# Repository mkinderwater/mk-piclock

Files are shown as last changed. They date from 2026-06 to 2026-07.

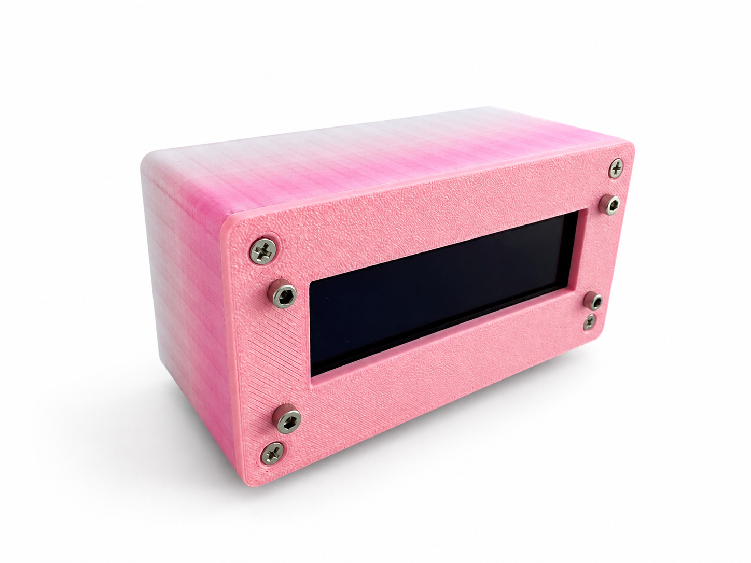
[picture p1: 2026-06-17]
side-picture.png

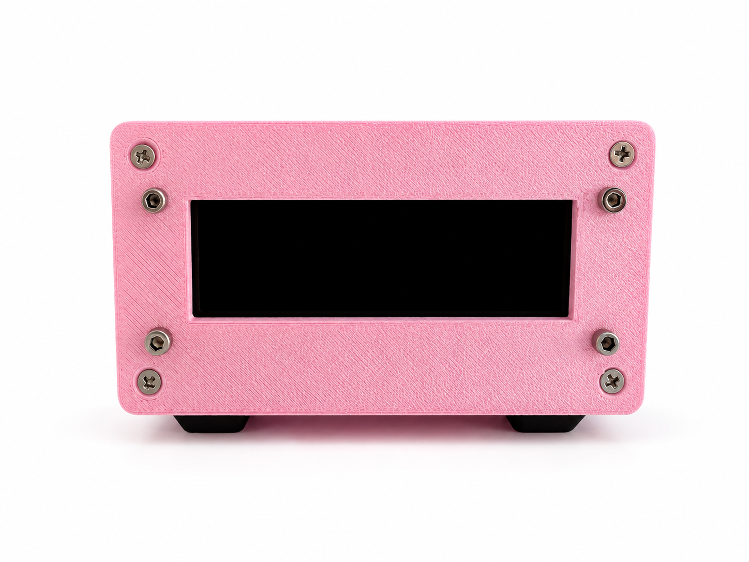
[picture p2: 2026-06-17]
front-picture.png

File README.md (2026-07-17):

# mk-piclock v1.8.1

mk-piclock is a native C bedside alarm clock for Raspberry Pi Zero and Zero 2 W. It drives a 256x64 SSD1322 OLED, MAX98357A I2S amplifier, speaker, TTP223B touch sensor, and optional RGB LED.

The project was created for my daughter Rylie. It is designed to behave like a simple bedside appliance, not a general-purpose computer.

## What's new in v1.8.1

- Standardized every GUI card heading with the same divider, spacing, and title alignment.
- Changed inactive sound status from `Quiet` to `None` across the GUI.
- Added consistent spacing between RGB Lighting and Global Controls.
- Removed the duplicate divider beneath the Web password description.
- Added matching headings to Story playback and Activity history.
- Updated browser asset versions so the polished GUI loads without stale cached files.
- Retained the production display and code cleanup introduced in v1.8.0.
- Kept HTTP API 1.25 and private IPC 16.

## Features

### Clock and display

- Large 12-hour or 24-hour clock
- Full date under the time
- Blinking colon
- Day and bedtime image libraries
- Automatic image rotation
- Plain-text Wi-Fi and alarm status footer
- Blinking `W.OFF` warning when wireless is disconnected
- OLED brightness control
- Separate bedtime schedule and brightness
- Yellow, green, or white panel selection for browser previews
- Built-in and uploaded TrueType or OpenType fonts
- Exact 256x64 live framebuffer preview on the Home page

The normal footer uses one baseline:

```text
W.095 | ALARM ON                  FRIDAY, JULY 17 2026
```

The last IPv4 octet is zero-padded. The alarm label changes between `ALARM ON` and `ALARM OFF`. When `wlan0` loses carrier or its IPv4 address, `W.OFF` blinks. The clock and alarms continue locally, but the browser and network time synchronization remain unavailable until Wi-Fi returns.

### Alarms

- Seven independent alarm slots
- Per-alarm time and weekday selection
- Specific or random uploaded music
- Separate starting and final volume
- Volume ramp across the song
- Next alarm shown on Home and System
- Last successful alarm recorded on System

#### Alarm safety

When an alarm starts:

- the selected song repeats until the touch sensor is pressed
- browser stop controls cannot dismiss the alarm
- an unreadable or missing song falls back to the protected built-in alarm
- the alarm stops after 30 minutes if nobody presses the sensor

The fallback alarm is installed at:

```text
/opt/mk-piclock/assets/default-alarm.mp3
```

It is retained during factory reset and is not part of the user music library.

### Kid-friendly touch control

- Press while an alarm is active: dismiss the alarm
- Short press while music or a story is playing: stop the audio
- Hold, then release: play a random song
- Keep holding the sensor: open the OLED network diagnostic screen
- Tap while diagnostics are open: close diagnostics
- Ten short taps within eight seconds: play a random story when Story Mode is enabled
- Any touch press: blink the RGB LED using the selected touch-feedback colour

The music action runs only when the sensor is released. Keep holding to open diagnostics instead, so the same press cannot start music. A diagnostic hold is not counted toward Story Mode.

Alarms cannot be dismissed from the browser. The physical touch sensor must be pressed.

#### OLED network diagnostics

Simply hold down the touch sensor to open the diagnostic screen. It shows:

- Wi-Fi network name
- Wi-Fi signal strength
- IP address
- hostname

It closes after 30 seconds or immediately when the touch sensor is tapped. Network values refresh while the screen is open.

### Bedtime behaviour

Bedtime mode uses its own schedule, image library, and brightness. It lets the clock remain useful at night without keeping the OLED unnecessarily bright.

Day Images and Bedtime Images are stored separately. During bedtime, the clock uses bedtime artwork and the configured bedtime brightness. Parents can disable touch-started music during bedtime while leaving alarms enabled.

### Messages

Parents can send a message to the OLED:

- immediately
- after 10, 30, or 60 seconds
- at a browser-local date and time within the next 30 days

A message can use:

- text only
- a specific Day Image
- a specific Bedtime Image
- a random Day Image
- a random Bedtime Image
- an image without text

One future message can be pending. A new scheduled message replaces the existing one. Pending messages survive a core restart. Each message can optionally play the built-in short chime when it appears. The chime is skipped when other audio is already playing.

The preview is rendered by `mk-piclock-core` using the same framebuffer, font measurements, word wrapping, image placement, centring, grayscale, and brightness rules as the physical OLED.

### Images

Day Images and Bedtime Images each support:

- PNG upload
- OLED conversion
- paged library review
- individual deletion
- delete all
- download all original PNG files as a ZIP

The download ZIP excludes converted `.raw` files.

### Music

Uploaded MP3 files are decoded and re-encoded inside `mk-piclock-api`. No shell command or external encoder is launched.

The recommended profile is:

- mono
- 96 kbps CBR
- 44.1 kHz
- 16 kHz low-pass

The Music page includes:

- multiple-file upload
- selected-file count and total upload size before upload
- upload and processing progress for queued and active jobs
- play, stop, and delete controls
- global volume
- optional encoding settings
- title, artist, album, year, track, genre, duration, bitrate, sample rate, channel, MPEG layer, and file size when available

Long `Title - Artist` text scrolls across the OLED. Short text remains centred.

Before OLED rendering, the title and artist are filtered against the built-in 5x7 glyph set. Unsupported Unicode, emoji, and symbols are omitted instead of becoming question marks. Filtering affects only the OLED copy. Original ID3 metadata remains available in the browser and API.

#### Upload queue rule

A batch of MP3 files may be uploaded at one time. A new upload is refused while any song from the current batch is queued or processing.

The full selection is validated and staged before any job is queued. If staging or queueing fails, the staged files are rolled back instead of leaving a partial batch. This keeps upload validation and transcoding from competing for CPU, memory, and storage on the Raspberry Pi.

**Clear Queue** deletes waiting jobs and their temporary source files. It does not interrupt the file currently transcoding.

### Stories

Story Mode uses a separate MP3 library stored under `assets/stories`. It can be enabled or disabled by a parent from the Stories page and has its own volume control.

When the touch sensor is tapped ten times within eight seconds:

1. a random story is selected
2. the OLED clears and shows up to five random Bedtime Images
3. the configurable intro message appears, defaulting to `STORY MODE!`
4. after three seconds, the selected story title appears in the normal clock footer
5. after four more seconds, the standard date returns while the story keeps playing

A single touch stops the story. Stories are not used by alarms and are not included in backups.

### RGB activity lighting

A common-cathode RGB LED can use a separate profile for each activity:

- Alarm
- Bedtime
- Message
- Music
- Daytime
- Stories

Each profile supports a solid colour, a fade between two colours, or rainbow mode. Brightness and the full effect-cycle time are configurable. The Lighting page can preview unsaved settings for ten seconds and includes red, green, blue, and white wiring tests.

Touch feedback is handled as a high-priority temporary LED scene while the touch sensor is pressed. Its colour and brightness live under Lighting, Global Controls, so it can stay consistent no matter which activity profile is currently active. The default touch feedback is a white blink.

Global controls provide a master switch, maximum brightness, per-channel calibration, optional idle-off behaviour, a gradual fade before bedtime, and touch-blink settings. Profile previews and wiring tests may temporarily bypass the master switch. A touch press briefly takes priority while pressed, then the normal alarm, message, story, music, bedtime, or daytime scene resumes.

The driver uses 200 Hz batched trailing-edge software PWM with 32 stable duty levels. A modest real-time priority is applied only to the LED timing thread, and missed low-brightness pulses are skipped rather than emitted late. Scene changes crossfade over 350 ms except alarms, which apply immediately. Repeated GPIO write failures disable lighting and appear in status and diagnostics.

The runtime priority after touch feedback is Alarm, Message, Stories, Music, Bedtime, then Daytime.

## Web interface

The GUI is organized by task.

### Everyday

- Home
- Alarms
- Messages
- Music
- Lighting
- Stories
- Day Images
- Bedtime Images

### Settings

- Display
- System

### Optional password

The web interface opens directly when no password exists. When a password is configured, the GUI asks for it before loading clock controls. The password can be set, changed, or removed from System. It is intentionally simple and stored as plain text for use only on a trusted home network.

### Always-visible confirmations

Save, test, delete, upload, and other action confirmations appear in a fixed floating notice. Feedback remains readable at any scroll position instead of appearing inside a section that may be off-screen.

### System diagnostics

The System page provides live diagnostics without launching external commands.

#### Network

- IP address
- hostname
- SSID
- active interface
- Wi-Fi signal percentage and dBm

#### Time

- system-time validity
- NTP synchronization state
- a prominent Home-page warning when time is not synchronized

#### Device identity

- short Inventory ID derived from the Raspberry Pi board serial
- full Raspberry Pi board serial
- Raspberry Pi board revision
- OS machine ID
- CPU signature for processor identification

Use the Inventory ID or Raspberry Pi serial to track a physical clock. The OS machine ID can change after reimaging, and the CPU signature is not unique.

#### Release and Raspberry Pi platform

- installed release version
- HTTP API version
- API compile date and time
- Raspberry Pi model
- operating system name
- OS version and codename
- kernel version
- CPU architecture
- system uptime
- CPU temperature

#### Storage and SD card

- used, available, and total system storage
- Day Images directory size and file count
- Bedtime Images directory size and file count
- music directory size and file count
- stories directory size and file count
- fonts directory size and file count
- system drive
- root partition and filesystem
- root read/write state
- boot partition, filesystem, and mount point
- SD-card device and type
- product name
- capacity
- manufacturer ID
- OEM ID
- serial number
- manufacture date
- CID

#### Service and clock health

- API health
- core connection
- OLED state
- touch-sensor state
- next alarm
- last successful alarm

**Download Diagnostic Report** saves the same information as a text file for support or troubleshooting.

### Backup and reset

The System page can:

- download a backup ZIP
- restore a backup created by mk-piclock
- factory reset settings and user-added assets

Backups include:

- alarms
- display and bedtime settings
- clock name and personalization
- scheduled-message data
- Day Images
- Bedtime Images
- uploaded fonts

Restore accepts only a validated mk-piclock backup ZIP. Paths, metadata, stored entries, sizes, and CRC values are checked before files are activated. Existing settings, images, and fonts are staged first and restored if the operation fails. Uploaded music and stories are not included in backups. Restore has no music or story handling, and both current libraries remain unchanged.

Restore is blocked while an alarm is active. Factory reset is blocked while an alarm is active or music is processing. Factory reset still removes uploaded music and stories. The protected fallback alarm remains installed after a factory reset.

### Help

- Recent Activity

Technical details remain available in collapsed sections so normal controls stay simple.

## Network access

The web interface opens directly when no password is configured. A simple optional password can be set or removed from System. It is stored as plain text on the clock and is intended only to keep casual users out of the controls.

Any device that can reach TCP port 8080 can view and change the clock. Keep the clock on a trusted home network.

Do not:

- forward port 8080 through the router
- expose the clock directly to the internet
- place it on an untrusted guest or public network

The API still runs as a restricted system account and communicates with the hardware process through a private Unix socket.

## Architecture

mk-piclock uses two native services.

### `mk-piclock-core`

Owns:

- OLED and SPI
- GPIO and touch input
- ALSA audio playback
- alarms
- clock and message rendering
- bedtime behaviour
- persistent clock configuration
- event logging

### `mk-piclock-api`

Owns:

- local web GUI
- HTTP API
- upload validation
- PNG conversion
- MP3 transcoding
- music, story, and image libraries
- OpenAPI document

The services communicate through:

```text
/run/mk-piclock/core.sock
```

The private binary protocol is IPC version 16.

## Command-free runtime

The running core and API do not use:

- `exec*()`
- `system()`
- `popen()`
- `posix_spawn()`
- `fork()` or `vfork()`

MP3 decoding, MP3 encoding, ZIP backup and restore, network inspection, platform reporting, and storage inspection run in-process through libraries and direct Linux interfaces.

The Makefile and installation steps use normal shell tools. This restriction applies to the installed runtime services.

## Time and NTP on Raspberry Pi OS Trixie

mk-piclock reads the Linux system clock. It does not contact an NTP server itself.

Raspberry Pi OS Lite based on Debian 13 Trixie normally uses `systemd-timesyncd` for network time synchronization. Set the timezone and confirm synchronization during installation:

```bash
sudo timedatectl set-timezone America/Edmonton
sudo timedatectl set-ntp true

timedatectl status
timedatectl show -p NTPSynchronized
```

Expected results include:

```text
System clock synchronized: yes
NTP service: active
NTPSynchronized=yes
```

Without a battery-backed real-time clock, correct time after a power loss depends on the Pi restoring time and reaching a time source.

## Supported platform

Recommended operating system:

```text
Raspberry Pi OS Lite
Debian 13 Trixie
```

Recommended hardware:

- Raspberry Pi Zero W or Zero 2 W
- SSD1322 256x64 OLED
- MAX98357A I2S amplifier
- 4-ohm, 3-watt speaker
- TTP223B touch sensor
- common-cathode RGB LED with one resistor per colour channel

See `pinouts.md` before applying power.

## Build dependencies

```bash
sudo apt update
sudo apt install --no-install-recommends -y \
  build-essential \
  pkg-config \
  libgpiod-dev \
  libpng-dev \
  libfreetype-dev \
  libasound2-dev \
  libmpg123-dev \
  libmp3lame-dev \
  libmicrohttpd-dev \
  unzip
```

`libmp3lame-dev` provides the in-process MP3 encoder.

## Quick installation

After configuring SPI and the MAX98357A overlay as described in `INSTALL.md`:

```bash
make clean
make -j2
make install
sudo systemctl restart mk-piclock-core.service mk-piclock-api.service
```

Open:

```text
http://<clock-ip>:8080/
```

Do not run `sudo make install`. The Makefile invokes `sudo` only for privileged installation steps.

## Storage

The installer and services only create the storage and runtime directories used by the clock. No old `auth`, `faces`, `bedtime-faces`, or `bedtime_faces` directories are created.

```text
/opt/mk-piclock/assets/images
/opt/mk-piclock/assets/bedtime-images
/opt/mk-piclock/assets/music
/opt/mk-piclock/assets/music/.processing
/opt/mk-piclock/assets/stories
/opt/mk-piclock/assets/fonts
/opt/mk-piclock/assets/default-alarm.mp3
/opt/mk-piclock/config/clock.conf
/opt/mk-piclock/config/event.log
/run/mk-piclock/core.sock
```

## Service logs

```bash
sudo journalctl -b -u mk-piclock-core.service -n 100 --no-pager
sudo journalctl -b -u mk-piclock-api.service -n 100 --no-pager
```

Follow both services:

```bash
sudo journalctl -f \
  -u mk-piclock-core.service \
  -u mk-piclock-api.service
```

## Known limitations

- The MAX98357A and speaker may make a small pop when audio starts or stops.
- **Clear Queue** removes waiting MP3 jobs but does not cancel the active transcode.
- The clock has no built-in battery-backed real-time clock. Accurate time after startup depends on Linux time restoration or NTP. The GUI warns when the clock is not synchronized.
- Restore accepts backup ZIP files generated by mk-piclock. Other ZIP compression formats are rejected.
- The optional GUI password is stored as plain text and is not strong security. Keep the clock on a trusted home network and do not expose port 8080 to the internet.
- USB-C power behaviour depends on the power board used in the enclosure. A USB-A to USB-C cable is often the safest choice for simple 5 V boards that do not implement USB-C power negotiation correctly.
- The physical OLED colour is fixed by the panel. The GUI colour choice changes browser previews only.
- Some network or SD-card fields can show **Unavailable** when the Linux driver does not expose the value.
- The API service sandbox remains restricted. Network detection uses direct IPv4 ioctls instead of netlink discovery.

## Versions

```text
Product:     1.8.1
HTTP API:    1.25
Private IPC: 16
```

Install the core and API from the same release, then restart both services. Installation replaces the complete web tree, and every GUI asset uses `Cache-Control: no-store`, preventing retired or cached files from surviving an upgrade.

## Documentation

- Build and install: `INSTALL.md`
- Hardware wiring: `pinouts.md`
- Version history: `CHANGELOG.md`
- HTTP API: `ADDON_API.md`
- OpenAPI schema: `api/openapi-v1.json`
- Current release summary: `RELEASE_NOTES.md`

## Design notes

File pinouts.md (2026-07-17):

# mk-piclock v1.8.1 Pinouts

This document covers the Raspberry Pi GPIO header, SSD1322 OLED, MAX98357A I2S amplifier, speaker, TTP223B touch sensor, and common-cathode RGB LED used by mk-piclock.

The software uses **BCM GPIO numbering**. Physical pin numbers refer to the Raspberry Pi 40-pin header.

## Complete connection table

| Device | Device signal | Raspberry Pi signal | BCM GPIO | Physical pin | Direction |
| --- | --- | --- | ---: | ---: | --- |
| External 5 V supply | +5 V | Pi 5 V input | - | 4 | Supply to Pi |
| External 5 V supply | GND | Pi ground | - | 9 | Supply to Pi |
| SSD1322 OLED | VCC | 3.3 V | - | 1 | Pi to OLED |
| SSD1322 OLED | GND | Ground | - | 6 | Common ground |
| SSD1322 OLED | DIN / MOSI / D1 | SPI0 MOSI | 10 | 19 | Pi to OLED |
| SSD1322 OLED | CLK / SCLK / D0 | SPI0 SCLK | 11 | 23 | Pi to OLED |
| SSD1322 OLED | CS | SPI0 CE0 | 8 | 24 | Pi to OLED |
| SSD1322 OLED | DC / A0 | Data/command | 25 | 22 | Pi to OLED |
| SSD1322 OLED | RST / RES | Reset | 27 | 13 | Pi to OLED |
| MAX98357A amp | VIN | 5 V | - | 2 | Pi to amp |
| MAX98357A amp | GND | Ground | - | 14 | Common ground |
| MAX98357A amp | BCLK | PCM clock | 18 | 12 | Pi to amp |
| MAX98357A amp | LRC / LRCLK / WS | PCM frame sync | 19 | 35 | Pi to amp |
| MAX98357A amp | DIN | PCM data | 21 | 40 | Pi to amp |
| MAX98357A amp | SD / EN | Not connected | - | - | Module default |
| TTP223B touch | VCC | 3.3 V | - | 17 | Pi to sensor |
| TTP223B touch | GND | Ground | - | 39 | Common ground |
| TTP223B touch | OUT / SIG | Digital input | 20 | 38 | Sensor to Pi |
| RGB LED | Red anode through resistor | Digital PWM output | 5 | 29 | Pi to LED |
| RGB LED | Green anode through resistor | Digital PWM output | 6 | 31 | Pi to LED |
| RGB LED | Blue anode through resistor | Digital PWM output | 13 | 33 | Pi to LED |
| RGB LED | Common cathode | Ground | - | 30 | Common ground |
| Speaker | `+` | MAX98357A `SPK+` | - | - | Amp to speaker |
| Speaker | `-` | MAX98357A `SPK-` | - | - | Amp to speaker |

The external regulated 5 V supply powers the Raspberry Pi through physical pin 4, with supply ground on physical pin 9. The amplifier uses physical pins 2 and 14, so no power connector is physically shared. Raspberry Pi pins 2 and 4 are still electrically connected to the same internal 5 V rail, and all ground pins are common. Do not connect USB power while the header supply is connected.

The build has two 3.3 V consumers: OLED VCC and TTP223B VCC. They use separate Raspberry Pi header pins. Leave the MAX98357A SD / EN pad unconnected.

## Raspberry Pi 40-pin header map

```text
                         Raspberry Pi GPIO header

OLED VCC       <- 3.3V       (1)  (2)  5V          -> MAX98357A VIN
                              (3)  (4)  5V          <- EXTERNAL +5V INPUT
                              (5)  (6)  GND         -> OLED GND
                              (7)  (8)
EXTERNAL GND    -> GND         (9) (10)
                             (11) (12) GPIO18       -> MAX98357A BCLK
OLED RST       <- GPIO27    (13) (14) GND          -> MAX98357A GND
                             (15) (16)
TTP223B VCC    <- 3.3V      (17) (18)
OLED MOSI      <- GPIO10    (19) (20) GND
                 GPIO9     (21) (22) GPIO25       -> OLED DC
OLED SCLK      <- GPIO11    (23) (24) GPIO8        -> OLED CS
                 GND       (25) (26)
                             (27) (28)
RGB RED        <- GPIO5     (29) (30) GND          -> RGB COMMON CATHODE
RGB GREEN      <- GPIO6     (31) (32)
RGB BLUE       <- GPIO13    (33) (34) GND
MAX98357A LRC  <- GPIO19    (35) (36)
                             (37) (38) GPIO20       -> TTP223B OUT
TTP223B GND    <- GND       (39) (40) GPIO21       -> MAX98357A DIN
```

Pin 1 is the 3.3 V corner pin. Confirm the header orientation before applying power.

## SSD1322 OLED

The core opens `/dev/spidev0.0`, which uses SPI0 CE0.

```text
SSD1322 OLED          Raspberry Pi
-----------------------------------------------
VCC                -> 3.3 V, physical pin 1
GND                -> GND, physical pin 6
DIN / MOSI / D1    -> GPIO10, physical pin 19
CLK / SCLK / D0    -> GPIO11, physical pin 23
CS                 -> GPIO8 CE0, physical pin 24
DC / A0            -> GPIO25, physical pin 22
RST / RES           -> GPIO27, physical pin 13
```

OLED settings compiled into `mk-piclock.c`:

```text
SPI device: /dev/spidev0.0
SPI mode:   0
SPI speed:  4 MHz
DC:         BCM GPIO25
RST:        BCM GPIO27
```

Notes:

- The OLED does not use SPI MISO. GPIO9, physical pin 21, remains unused.
- Connect CS to CE0. Do not tie CS low when using `/dev/spidev0.0` unless the specific module requires it and no other SPI device shares the bus.
- SSD1322 module header order varies. Follow the signal labels printed on the module, not the position shown in a seller photograph.
- This project wiring uses 3.3 V for the OLED. Confirm the module is configured for 4-wire SPI.

## MAX98357A I2S amplifier

```text
MAX98357A             Raspberry Pi
-----------------------------------------------
VIN                -> 5 V, physical pin 2
GND                -> GND, physical pin 14
BCLK               -> GPIO18, physical pin 12
LRC / LRCLK / WS   -> GPIO19, physical pin 35
DIN                -> GPIO21, physical pin 40
SD / EN            -> Not connected
```

Required `/boot/firmware/config.txt` settings:

```ini
dtparam=audio=off
dtoverlay=max98357a,no-sdmode
```

`no-sdmode` means mk-piclock does not control the amplifier SD or EN input from a GPIO. On the tested module, leaving SD / EN unconnected allows the module's onboard bias network to enable playback and select its default mono mix. Do not connect SD / EN to a Raspberry Pi GPIO or directly to 3.3 V.

### Audio startup click

A small click when playback starts is accepted in this release. SD / EN remains unconnected, and mk-piclock does not add amplifier switching, a persistent silence stream, or other click-suppression logic.

## Speaker

Connect the speaker only to the MAX98357A output:

```text
MAX98357A SPK+  -> Speaker +
MAX98357A SPK-  -> Speaker -
```

Important:

- Do not connect either speaker terminal to Raspberry Pi ground.
- The MAX98357A speaker output is differential.
- Use one compatible 4 to 8 ohm speaker.
- Disconnect power before changing speaker or amplifier wiring.

## TTP223B touch sensor

```text
TTP223B               Raspberry Pi
-----------------------------------------------
VCC                -> 3.3 V, physical pin 17
GND                -> GND, physical pin 39
OUT / SIG          -> GPIO20, physical pin 38
```

The core reads GPIO20 as an active-high input and applies software debounce.

```text
Short press:   stop current audio
Hold 3 seconds: play random uploaded music
```

Power the TTP223B from **3.3 V**. Do not power it from 5 V while OUT is directly connected to a Raspberry Pi GPIO.

## Common-cathode RGB LED

```text
RGB LED                Raspberry Pi
Red anode, resistor -> GPIO5, physical pin 29
Green anode, resistor -> GPIO6, physical pin 31
Blue anode, resistor -> GPIO13, physical pin 33
Common cathode      -> GND, physical pin 30
```

Use one 220 to 330 ohm current-limiting resistor on each colour channel. The software drives the three anodes active-high using 200 Hz batched trailing-edge PWM with 32 stable duty levels. This wiring is for a common-cathode LED. A common-anode module requires inverted output logic and is not supported by this release.

The Lighting page includes direct red, green, blue, and white wiring tests. These tests temporarily bypass the master switch, global brightness ceiling, and colour calibration so each physical channel can be checked independently.

## GPIOs used by mk-piclock

| BCM GPIO | Physical pin | Purpose |
| ---: | ---: | --- |
| 5 | 29 | RGB LED red |
| 6 | 31 | RGB LED green |
| 8 | 24 | OLED SPI CE0 / CS |
| 10 | 19 | OLED SPI MOSI |
| 11 | 23 | OLED SPI clock |
| 13 | 33 | RGB LED blue |
| 18 | 12 | MAX98357A BCLK |
| 19 | 35 | MAX98357A LRC / LRCLK |
| 20 | 38 | TTP223B OUT |
| 21 | 40 | MAX98357A DIN |
| 25 | 22 | OLED DC |
| 27 | 13 | OLED reset |

## Pre-power checklist

- Confirm the external supply is a regulated 5 V source suitable for the Pi and amplifier load.
- Connect external +5 V to physical pin 4 and external ground to physical pin 9.
- Do not connect USB power while the GPIO header supply is connected.
- Confirm pin 1 orientation on the Raspberry Pi header.
- Confirm every module shares Raspberry Pi ground.
- Confirm the OLED VCC wire is on 3.3 V, not a GPIO.
- Confirm the touch sensor VCC wire is on 3.3 V.
- Confirm the RGB LED is common-cathode and each colour has a current-limiting resistor.
- Confirm the amplifier SD / EN pad is not connected.
- Confirm amplifier DIN is connected to GPIO21, physical pin 40, and is not tied to 3.3 V.
- Confirm the speaker connects to `SPK+` and `SPK-`, not ground.
- Check for solder bridges before applying power.
- Enable SPI and the MAX98357A overlay before starting the services.

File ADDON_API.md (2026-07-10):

# mk-piclock HTTP API 1.25

The GUI and add-ons use the HTTP API on port 8080.

```text
http://<clock-ip>:8080/api/v1
```

Most routes are directly available when no password is configured. When a password exists, authenticate through `/api/v1/auth/login`; the API returns a session cookie used by the GUI. The password is stored as plain text and is intended only for a trusted home network. Do not expose port 8080 to the internet.

## Optional password

```http
GET  /api/v1/auth/status
POST /api/v1/auth/login
POST /api/v1/auth/password
```

`GET /api/v1/auth/status` reports whether a password exists and whether the current browser cookie is valid. `POST /api/v1/auth/login` accepts `password`. `POST /api/v1/auth/password` sets a new password or removes it when `password` is empty. The discovery endpoint and the two status/login routes remain public so the GUI can decide whether to show the prompt.

## Discovery and status

```http
GET /api/v1
GET /api/v1/capabilities
GET /api/v1/openapi.json
GET /api/v1/health
GET /api/v1/status
GET /api/v1/diagnostics
GET /api/v1/diagnostics/report
```

## Images

```http
GET  /api/v1/assets/images
GET  /api/v1/assets/bedtime-images
GET  /api/v1/assets/images/source?file=<raw-name>
GET  /api/v1/assets/bedtime-images/source?file=<raw-name>
GET  /api/v1/assets/images/download
GET  /api/v1/assets/bedtime-images/download
POST /api/v1/assets/images/upload
POST /api/v1/assets/bedtime-images/upload
POST /api/v1/assets/images/delete
POST /api/v1/assets/bedtime-images/delete
POST /api/v1/assets/images/delete-all
POST /api/v1/assets/bedtime-images/delete-all
```

The Day and Bedtime download routes return ZIP archives containing only original PNG files.

## Music

```http
GET  /api/v1/assets/music
POST /api/v1/assets/music/upload
GET  /api/v1/assets/music/jobs
POST /api/v1/assets/music/jobs/clear
POST /api/v1/assets/music/delete
POST /api/v1/assets/music/delete-all
```

MP3 upload settings include bitrate, sample rate, and low-pass frequency. One request may include 1 to 32 MP3 files. The full selection is validated and queued as one batch, and uploads are refused while any job is queued or processing. `POST /api/v1/assets/music/jobs/clear` removes waiting jobs but does not interrupt the active transcoder.

## Display and messages

```http
POST /api/v1/display/action
GET  /api/v1/display/preview
POST /api/v1/display/brightness-preview
POST /api/v1/display/message
POST /api/v1/display/message/preview
```

`POST /api/v1/display/message/preview` accepts `image_file`, `image_bedtime`, and `message_text`, then returns the exact packed 4-bit 256x64 framebuffer without changing the physical OLED.

Messages accept:

```text
image_file=<image raw filename, optional; empty selects a random image>
image_bedtime=0 for Day Images or 1 for Bedtime Images
message_text=<optional text; an image-only message is allowed>
delay_seconds=0, 10, 30, or 60
scheduled_at=<Unix timestamp, optional, within 30 days>
notification_sound=0 or 1; 1 plays the built-in chime when displayed
```

`GET /api/v1/diagnostics` returns release and compile information, network and NTP state, platform, device-identity, and operating-system details, used and available storage, asset directory sizes and file counts, root and boot filesystem details, SD-card identity, temperature, core/API, OLED, touch, and alarm health. `GET /api/v1/diagnostics/report` downloads the same information as text. Diagnostics are gathered in-process from Linux APIs and files under `/etc`, `/proc`, and `/sys`; the API does not launch system commands.

## Backup, restore, and reset

```http
GET  /api/v1/backup/download
POST /api/v1/backup/restore
POST /api/v1/factory-reset
```

Restore expects one multipart ZIP created by the download route. Backup ZIPs contain configuration, images, and fonts but exclude uploaded music and stories. Music and stories are outside the backup and restore system, so restore leaves both current libraries unchanged. Factory reset requires `confirm=RESET`. Restore and reset are refused while an alarm is active. Factory reset is also refused while music is processing.

## Configuration

```http
POST /api/v1/config/alarms
POST /api/v1/config/audio
POST /api/v1/config/personalization
POST /api/v1/config/display
POST /api/v1/config/led
```

Display configuration accepts `bedtime_music_enabled=0` to block touch-started and browser-started music during bedtime. Alarms remain enabled.

## Alarm behaviour

Alarms loop until the physical touch sensor is pressed or the 30-minute safety limit is reached. Browser stop requests return HTTP 409 while an alarm is active. If the selected MP3 is missing or unreadable, the protected built-in alarm is used.

`GET /api/v1/status` includes `next_alarm_at`, `next_alarm_text`, `last_successful_alarm`, and `bedtime_music_enabled`.

## RGB lighting

Save one activity profile:

```http
POST /api/v1/config/led
Content-Type: application/x-www-form-urlencoded

scene=alarm&effect=fade&brightness=100&color1=%23ff0000&color2=%23ffa000
```

Valid scenes are `alarm`, `bedtime`, `message`, `music`, `daytime`, and `stories`. Valid effects are `solid`, `fade`, and `rainbow`. Brightness is 0 through 100. Colours use `#RRGGBB`.

Preview unsaved settings for up to 30 seconds:

```http
POST /api/v1/led/preview
Content-Type: application/x-www-form-urlencoded

scene=music&effect=rainbow&brightness=70&color1=%23ff0000&color2=%230000ff&hold_seconds=10
```

`GET /api/v1/status` includes `led_ok`, `led_scene`, `led_colour`, `led_output`, `led_gpio`, PWM diagnostics, global calibration settings, preview state, bedtime-fade state, and all six `led_profiles`.

Activity priority is Alarm, Message, Stories, Music, Bedtime, then Daytime. Alarm lighting cannot be overridden by a preview.

`POST /api/v1/config/led-global` saves the master switch, brightness ceiling, RGB gains, idle-off option, and bedtime-fade duration. `POST /api/v1/config/led` also accepts `cycle_seconds` from 2 to 60. Preview requests may set `bypass_master=1`; direct wiring tests also use `raw_output=1` to bypass calibration and limits.

## Activity

```http
GET  /api/v1/logs
POST /api/v1/logs/clear
```

## Compatibility

```text
HTTP API:    1.25
Private IPC: 16
```

See `api/openapi-v1.json` for the complete schema.

## Story Mode

- `GET /api/v1/assets/stories` lists story MP3 files and Story Mode settings.
- `POST /api/v1/assets/stories/upload` uploads one validated MP3 into the separate Stories library.
- `POST /api/v1/assets/stories/delete` deletes one story.
- `POST /api/v1/assets/stories/delete-all` clears the story library.
- `POST /api/v1/display/action` with `do=play-story` plays a selected story or a random story when `file` is blank.
- `POST /api/v1/config/audio` accepts `story_enabled`, `story_volume`, and `story_message`.

Story Mode must be enabled before a story can be started. Ten short touch presses within eight seconds start a random story. An eight-second hold opens the OLED network diagnostic screen and is not counted as a Story Mode tap.

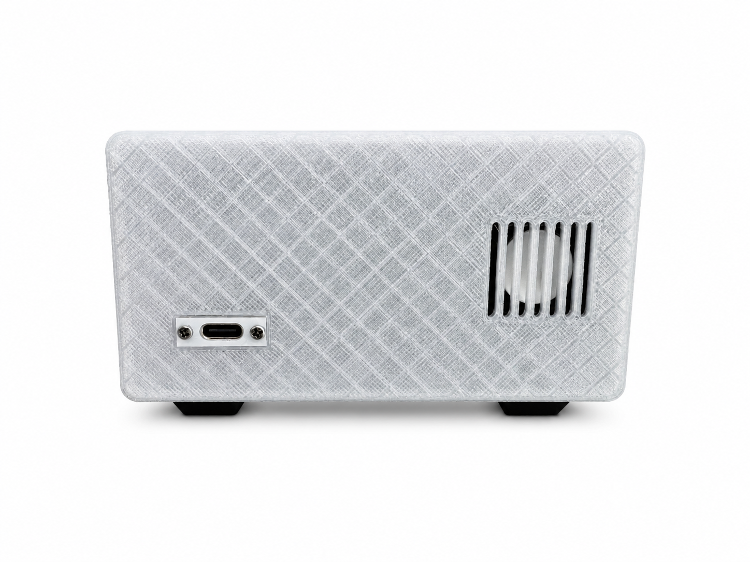
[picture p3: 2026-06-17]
back-picture.png

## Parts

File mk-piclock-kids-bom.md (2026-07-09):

# mk-piclock Kids BOM

## Build scope

This BOM is for one **mk-piclock kids** unit.

Assumptions:

- 1 Raspberry Pi Zero 2 WH per build
- 1 speaker per build
- 1 OLED display per build
- 1 RGB LED module per build
- 1 TP223B touch module per build
- 1 jumper wire set / ribbon cable per build
- 1 USB-C panel mount connector per build
- 4 rubber feet per build
- 1 MAX98357A I2S amplifier per build
- 1 USB-A to USB-C cable per build

## Per-unit BOM

| Item | Purchase Qty / Pack | Pack Price | Qty Used Per Build | Unit Cost Used | Extended Build Cost |
| --- | ---: | ---: | ---: | ---: | ---: |
| Raspberry Pi Zero 2 WH with pre-soldered headers | 1 | $53.95 | 1 | $53.95 | $53.95 |
| 4 Ohm 3W mini speaker with JST-PH2.0 2-pin terminal | 4 | $23.01 | 1 | $5.75 | $5.75 |
| 3.12 inch OLED display, 256x64, SSD1322 module | 2 | $58.10 | 1 | $29.05 | $29.05 |
| RGB LED module for Arduino / ESP32 / ESP8266 / Raspberry Pi | 10 | $22.38 | 1 | $2.24 | $2.24 |
| DAOKI TP223B touch switch module, 2-5.5V | 10 | $17.69 | 1 | $1.77 | $1.77 |
| MECCANIXITY female-to-female 40-pin breadboard jumper wire / ribbon cable, 2.54mm pitch, 10cm | 1 | $10.49 | 1 | $10.49 | $10.49 |
| USB Type-C female panel mount connector, reversible solder type | 10 | $16.29 | 1 | $1.63 | $1.63 |
| Black rubber feet, 16-piece pack, self-adhesive bumper pads | 16 | $10.99 | 4 | $0.69 | $2.75 |
| I2S 3W Class D amplifier board, MAX98357 / MAX98357A | 1 | $7.59 | 1 | $7.59 | $7.59 |
| 6 ft USB-A to USB-C cable, pack of 5 | 5 | $17.99 | 1 | $3.60 | $3.60 |

## Estimated cost per unit

**Estimated electronics / hardware cost per mk-piclock kids unit: $118.83 CAD**

## Not included

This BOM does **not** include:

- PLA or ASA filament
- Screws
- USB-A 5V 2A AC-to-DC adapter
- Solder, heat-shrink, ferrules, terminals, or other shop consumables
- SD card
- Shipping, taxes, duties, or marketplace fees

## Notes

- Rubber feet were calculated as a 16-piece pack with 4 feet used per build.
- Jumper wire cost was counted as one full purchase per build because no pack quantity was provided.
- MAX98357A amplifier cost was counted as one full purchase per build because no pack quantity was provided.
- Prices are based only on the values provided and were not checked against current supplier pricing.

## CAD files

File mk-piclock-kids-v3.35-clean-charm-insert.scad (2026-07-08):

// mk-piclock-kids case V3.35 cleaned charm insert
// Base geometry retained from mk-piclock-case-v2.51.scad
// Lid geometry retained from mk-piclock-case-v2.52F-marked.scad
//
// Released: 2026-06-28
//
// Production overview:
// 1. Fixed component coordinates replace historical movement-offset chains.
// 2. Shared self-tapping pilot and control-screw dimensions are centralized.
// 3. Touch sensor retains three blind pilots and two hidden tool-access holes.
// 4. The touch exterior now uses the adult production right-side half-circle
//    crescent around the sensing area.
// 5. Paired raised music-note icons shield the upper-left touch screw area,
//    with both notes facing toward the lid.
// 6. The touch PCB, sensing recess, screw locations, and tool-access holes remain
//    unchanged.
// 7. The v3.17 transparent charm cap is integrated as the charm insert.
// 8. Its hollow 6.4mm cap projects outward for LED diffusion while the 18mm
//    exterior flange overlaps the straight 14mm wall opening by 2mm per side.
// 9. Four crush ribs and a slotted, tapered two-petal snap collar lock behind
//    the 3mm wall.
// 10. The matching insert prints face-down without supports.
// 11. Only the touch recess uses concealed roof relief.
// 12. Rubber-foot recesses remain 21mm with equal front-to-back spacing.
// 13. The same restrained cleanup is applied to the remaining case geometry:
//     rounded support fins, softer lid-mount edges, rounded speaker arms, and
//     cleaner LED and USB-C support transitions.
// 14. All component coordinates, wall thicknesses, openings, pilot locations,
//     and functional clearances remain unchanged.
// 15. No include or use statements are required.
//
// Units: mm

$fn = 64;

// Select: "base", "lid", "lid_print", "assembly", or "charm_insert".
part = "base";

fit_fudge = 0.3;

// Shared production hardware.
self_tap_pilot_d = 1.8;
control_screw_length = 5.0;
control_screw_head_d = 5.0;
control_screw_head_h = 1.6;
control_screw_shank_d = 2.5;
control_pilot_wall_stop = 0.20;

// FDM values used by actual geometry.
fdm_layer_h = 0.20;
fdm_union_overlap = 0.40;
fdm_pilot_lead_in = 0.60;

// Restrained cleanup values. These only soften support geometry and do not
// move any component, opening, pilot, or case wall.
clean_support_fn = 32;
clean_lid_mount_r = 0.90;
clean_led_mount_r = 0.80;
clean_usb_support_r = 0.80;

// -----------------------------------------------------------------------------
// Case
// -----------------------------------------------------------------------------

case_w = 114;
case_h = 60;
case_d = 50;

wall = 3;
corner_r = 4;

lid_t = 3;
lip_depth = 6;
lip_clearance = 0.35;
lip_wall = 2.2;

assembly_lid_lift = 8;

// -----------------------------------------------------------------------------
// OLED module
// -----------------------------------------------------------------------------

oled_pcb_w = 100.5;
oled_pcb_h = 33.5;

oled_screen_w = 81.5;
oled_screen_h = 24.0;

oled_view_w = 76.7;
oled_view_h = 19.2;

oled_pcb_t = 1.6;

oled_hole_span_x = 95;
oled_hole_span_y = 28.5;

oled_x = (case_w - oled_pcb_w) / 2;
oled_y = (case_h - oled_pcb_h) / 2;

oled_screen_x = oled_x + (oled_pcb_w - oled_screen_w) / 2;
oled_screen_y = oled_y + (oled_pcb_h - oled_screen_h) / 2 + 2;

oled_view_x = oled_x + (oled_pcb_w - oled_view_w) / 2;
oled_view_y = oled_y + (oled_pcb_h - oled_view_h) / 2 + 2;

oled_hole_x_offset = (oled_pcb_w - oled_hole_span_x) / 2;
oled_hole_y_offset = (oled_pcb_h - oled_hole_span_y) / 2;

oled_m3_clearance_d = 3.0 + fit_fudge;
oled_m3_head_preview_d = 5.8;

oled_solder_joint_padding = 3.0;
oled_solder_padding_d = 6.4;

// -----------------------------------------------------------------------------
// Raspberry Pi Zero and amplifier
// -----------------------------------------------------------------------------

pi_w = 65;
pi_h = 30;
pi_corner_r = 3;

// Final production coordinates. Historical movement offsets are retired.
pi_x = 41.5;
pi_y = 24.5;

pi_holes = [
    [3.5, 3.5],
    [61.5, 3.5],
    [3.5, 26.5],
    [61.5, 26.5]
];

pi_standoff_h = 6;
pi_standoff_od = 5.8;
pi_standoff_pilot_d = self_tap_pilot_d;

pi_gusset_h = 4.5;
pi_gusset_w = 1.6;
pi_gusset_len = 6;

amp_w = 20;
amp_h = 19;
amp_corner_r = 2;
amp_hole_span = 12.5;
amp_x = 49.5;
amp_y = 5.0;
amp_hole_x = 59.5;

amp_standoff_h = pi_standoff_h;
amp_standoff_od = pi_standoff_od;
amp_standoff_pilot_d = self_tap_pilot_d;

amp_holes = [
    [amp_w / 2, amp_h / 2 - amp_hole_span / 2],
    [amp_w / 2, amp_h / 2 + amp_hole_span / 2]
];

amp_lower_hole_y = 8.25;
amp_upper_hole_y = 20.75;

// -----------------------------------------------------------------------------
// Speaker
// -----------------------------------------------------------------------------

speaker_w = 31;
speaker_h = 28;
speaker_center_x = 20.5;
speaker_center_y = 30.0;

speaker_baffle_h = 7;
speaker_mount_h = speaker_baffle_h;
speaker_mount_w = pi_standoff_od;
speaker_mount_pilot_d = self_tap_pilot_d;
speaker_mount_span = 38.0;

speaker_mount_support_w = speaker_mount_w;
speaker_mount_support_h = speaker_baffle_h;
speaker_support_wall_overlap = 0.8;

speaker_slot_w = 2.2;
speaker_slot_h = 22.0;
speaker_slot_gap = 1.25;
speaker_slot_count = 7;

speaker_baffle_wall = 1.4;
speaker_pocket_clearance = 1.0;
speaker_pocket_w = speaker_w + speaker_pocket_clearance;
speaker_pocket_h = speaker_h + speaker_pocket_clearance;
speaker_baffle_outer_w = speaker_pocket_w + speaker_baffle_wall * 2;
speaker_baffle_outer_h = speaker_pocket_h + speaker_baffle_wall * 2;
speaker_baffle_inner_w = speaker_pocket_w;
speaker_baffle_inner_h = speaker_pocket_h;
speaker_baffle_corner_r = 2.0;

speaker_wire_relief_w = 4.0;
speaker_wire_relief_depth = speaker_baffle_wall + 0.8;
speaker_wire_relief_h = speaker_baffle_h * 0.5;

// -----------------------------------------------------------------------------
// Pi connector preview coordinates
// -----------------------------------------------------------------------------

usb_centers_x = [52.5, 65.1];
micro_hdmi_center_x = 94.1;

// All external Pi-side openings, including microSD, remain closed.

// -----------------------------------------------------------------------------
// USB-C power insert
// -----------------------------------------------------------------------------

usb_c_panel_w = 20;
usb_c_panel_h = 7;
usb_c_panel_depth = 2.2;
usb_c_header_cutout_w = 12.2;
usb_c_header_cutout_h = 7;
usb_c_hole_span = 16;
usb_c_mount_pilot_d = pi_standoff_pilot_d;

usb_c_recess_fudge = 0.25;
usb_c_clearance_from_walls = 10.0;

usb_c_panel_x =
    case_w - wall - usb_c_clearance_from_walls - usb_c_panel_w;
usb_c_panel_y = wall + usb_c_clearance_from_walls;
usb_c_panel_center_x = usb_c_panel_x + usb_c_panel_w / 2;
usb_c_panel_center_y = usb_c_panel_y + usb_c_panel_h / 2;
usb_c_panel_z = 0;

usb_c_hole_centers = [
    [usb_c_panel_center_x - usb_c_hole_span / 2, usb_c_panel_center_y],
    [usb_c_panel_center_x + usb_c_hole_span / 2, usb_c_panel_center_y]
];

usb_c_support_rail_w = 1.4;
usb_c_support_rail_h = 5.0;
usb_c_support_end_w = 1.4;

usb_c_connector_preview_w = usb_c_header_cutout_w;
usb_c_connector_preview_d = usb_c_header_cutout_h;
usb_c_connector_preview_h = 6.0;

// -----------------------------------------------------------------------------
// Markings and rubber feet
// -----------------------------------------------------------------------------

base_part_number = "mk-piclock-kids v3.35";
base_part_number_size = 4.0;
base_part_number_h = 0.45;
base_part_number_x = pi_x + pi_w / 2;
base_part_number_y = pi_y + pi_h / 2;

// Raised on the lid underside, below the OLED PCB footprint.
// Mirrored so it reads correctly when viewing the removed lid from inside.
lid_part_number = "MK-PiClock-V2.3R";
lid_part_number_size = 3.4;
lid_part_number_h = 0.55;
lid_text_overlap = 0.05;
lid_part_number_x = case_w / 2;
lid_part_number_y = 11.0;

// Lid orientation marks, raised on the underside and clear of the OLED PCB.
lid_orientation_text_size = 3.6;
lid_orientation_text_h = 0.55;
lid_top_text_x = case_w / 2;
lid_top_clear_edge_y = case_h - (wall + lip_clearance + lip_wall);
lid_top_text_y = (oled_y + oled_pcb_h + lid_top_clear_edge_y) / 2;

usb_c_polarity_mark_size = 4.0;
usb_c_polarity_mark_h = 0.45;
usb_c_polarity_mark_y = usb_c_panel_y - 4.0;
usb_c_polarity_plus_x =
    usb_c_panel_center_x - usb_c_hole_span / 2;

rubber_foot_size = 21;
rubber_foot_recess_depth = 1.2;

// Equal front-to-back spacing: bottom margin = centre gap = lid-side margin.
rubber_foot_z_gap =
    (case_d - 2 * rubber_foot_size) / 3;

// Long-driver openings hidden beneath the right rubber feet.
rubber_foot_tool_access_d = 6.975;

rubber_foot_x_positions = [10, 83];

rubber_foot_z_positions = [
    rubber_foot_z_gap,
    rubber_foot_z_gap * 2 + rubber_foot_size
];
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

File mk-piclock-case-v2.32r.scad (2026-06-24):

// mk-piclock case V2.3R
// Base geometry retained from mk-piclock-case-v2.51.scad
// Lid geometry retained from mk-piclock-case-v2.52F-marked.scad
//
// Released: 2026-06-24
//
// Complete single-file OpenSCAD source. No include or use statements.
//
// Current touch-sensor design:
// 1. Normal case wall remains 3mm thick.
// 2. Touch target is a smooth 14mm circular depression.
// 3. Depression leaves exactly 1mm over the sensing electrode.
// 4. A raised 2mm right-hand crescent surrounds the circle.
// 5. Two diagonal mounts are retained:
//    - lower-left external M2.5 clearance screw
//    - upper-right internal blind pilot
// 6. Sensor remains lowered 2mm from its original position.
// 7. Upper-right touch pilot leaves exactly 1mm of exterior material.
// 8. Original OLED lid clearance holes and half-moon pads are restored.
// 9. No temperature or humidity sensor mount is included.
//
// Units: mm

$fn = 64;

// Select: "base", "lid", or "assembly".
part = "base";

fit_fudge = 0.3;

// -----------------------------------------------------------------------------
// Case
// -----------------------------------------------------------------------------

case_w = 114;
case_h = 60;
case_d = 50;

wall = 3;
corner_r = 4;

lid_t = 3;
lip_depth = 6;
lip_clearance = 0.35;
lip_wall = 2.2;

assembly_lid_lift = 8;

// -----------------------------------------------------------------------------
// OLED module
// -----------------------------------------------------------------------------

oled_pcb_w = 100.5;
oled_pcb_h = 33.5;

oled_screen_w = 81.5;
oled_screen_h = 24.0;

oled_view_w = 76.7;
oled_view_h = 19.2;

oled_pcb_t = 1.6;

oled_hole_span_x = 95;
oled_hole_span_y = 28.5;

oled_x = (case_w - oled_pcb_w) / 2;
oled_y = (case_h - oled_pcb_h) / 2;

oled_screen_x = oled_x + (oled_pcb_w - oled_screen_w) / 2;
oled_screen_y = oled_y + (oled_pcb_h - oled_screen_h) / 2 + 2;

oled_view_x = oled_x + (oled_pcb_w - oled_view_w) / 2;
oled_view_y = oled_y + (oled_pcb_h - oled_view_h) / 2 + 2;

oled_hole_x_offset = (oled_pcb_w - oled_hole_span_x) / 2;
oled_hole_y_offset = (oled_pcb_h - oled_hole_span_y) / 2;

oled_m3_clearance_d = 3.0 + fit_fudge;
oled_m3_head_preview_d = 5.8;
oled_m3_washer_preview_d = 7.0;
oled_m3_nut_preview_d = 6.4;

oled_solder_joint_padding = 3.0;
oled_solder_padding_d = 6.4;

// -----------------------------------------------------------------------------
// Raspberry Pi Zero and amplifier
// -----------------------------------------------------------------------------

pi_w = 65;
pi_h = 30;
pi_corner_r = 3;

pi_x = case_w - wall - 2 - pi_w;

board_gap = 2;
pi_shift_y = -1.5;

amp_w = 20;
amp_h = 19;
amp_corner_r = 2;
amp_hole_span = 12.5;
amp_y = wall + 2;

pi_y = amp_y + amp_h + board_gap + pi_shift_y;

pi_holes = [
    [3.5, 3.5],
    [61.5, 3.5],
    [3.5, 26.5],
    [61.5, 26.5]
];

pi_standoff_h = 6;
pi_standoff_od = 5.8;
pi_standoff_pilot_d = 1.8;

pi_gusset_h = 4.5;
pi_gusset_w = 1.6;
pi_gusset_len = 6;

amp_shift_x = 12;
amp_standoff_h = pi_standoff_h;
amp_standoff_od = pi_standoff_od;
amp_standoff_pilot_d = pi_standoff_pilot_d;

amp_hole_x = pi_x + 3.5 + amp_shift_x;
amp_x = amp_hole_x - amp_w / 2;

amp_holes = [
    [amp_w / 2, amp_h / 2 - amp_hole_span / 2],
    [amp_w / 2, amp_h / 2 + amp_hole_span / 2]
];

amp_lower_hole_y = amp_y + amp_h / 2 - amp_hole_span / 2;
amp_upper_hole_y = amp_y + amp_h / 2 + amp_hole_span / 2;

// -----------------------------------------------------------------------------
// Speaker
// -----------------------------------------------------------------------------

speaker_w = 31;
speaker_h = 28;

speaker_shift_x = -3;
speaker_shift_y = 0;
speaker_center_x = wall + (pi_x - wall) / 2 + speaker_shift_x;
speaker_center_y = case_h / 2 + speaker_shift_y;

speaker_mount_nominal_h = 7;
speaker_baffle_h = speaker_mount_nominal_h;
speaker_mount_h = speaker_baffle_h;
speaker_mount_w = pi_standoff_od;
speaker_mount_pilot_d = pi_standoff_pilot_d;
speaker_mount_span = 38.0;

speaker_mount_center_to_wall =
    (case_h - 2 * wall - speaker_mount_span) / 2;
speaker_mount_wall_clearance =
    speaker_mount_center_to_wall - speaker_mount_w / 2;

speaker_mount_support_w = speaker_mount_w;
speaker_mount_support_h = speaker_baffle_h;
speaker_support_wall_overlap = 0.8;

speaker_grill_d = 28;
speaker_slot_w = 2.2;
speaker_slot_h = 22.0;
speaker_slot_gap = 1.25;
speaker_slot_count = 7;

speaker_baffle_wall = 1.4;
speaker_pocket_clearance = 1.0;
speaker_pocket_w = speaker_w + speaker_pocket_clearance;
speaker_pocket_h = speaker_h + speaker_pocket_clearance;
speaker_baffle_outer_w = speaker_pocket_w + speaker_baffle_wall * 2;
speaker_baffle_outer_h = speaker_pocket_h + speaker_baffle_wall * 2;
speaker_baffle_inner_w = speaker_pocket_w;
speaker_baffle_inner_h = speaker_pocket_h;
speaker_baffle_corner_r = 2.0;

speaker_wire_relief_w = 4.0;
speaker_wire_relief_depth = speaker_baffle_wall + 0.8;
speaker_wire_relief_h = speaker_baffle_h * 0.5;

// -----------------------------------------------------------------------------
// Pi ports
// -----------------------------------------------------------------------------

usb_cutout_w = 10.5;
usb_cutout_h = 10;
usb_cutout_z = wall + pi_standoff_h + 1 - 2.5;

usb_centers_x = [
    pi_x + (pi_w - 54.0),
    pi_x + (pi_w - 41.4)
];

usb_side_pad = 8;

usb_slot_x =
    min(usb_centers_x[0], usb_centers_x[1])
    - usb_cutout_w / 2
    - usb_side_pad;

usb_slot_w =
    max(usb_centers_x[0], usb_centers_x[1])
    - min(usb_centers_x[0], usb_centers_x[1])
    + usb_cutout_w
    + usb_side_pad * 2;

sd_slot_w_original = 18;
sd_slot_trim_right = 4;
sd_slot_trim_foot_side = 1;
sd_slot_trim_hdmi_side = 1;
sd_slot_w =
    sd_slot_w_original
    - sd_slot_trim_right
    - sd_slot_trim_foot_side
    - sd_slot_trim_hdmi_side;

sd_slot_h = 6;
sd_slot_z = wall + pi_standoff_h;
sd_slot_y =
    pi_y + pi_h / 2
    - sd_slot_w_original / 2
    + sd_slot_trim_foot_side;

micro_hdmi_center_x = pi_x + (pi_w - 12.4);

// -----------------------------------------------------------------------------
// USB-C power insert
// -----------------------------------------------------------------------------

usb_c_panel_w = 20;
usb_c_panel_h = 7;
usb_c_panel_depth = 2.2;
usb_c_header_cutout_w = 12.2;
usb_c_header_cutout_h = 7;
usb_c_hole_span = 16;
usb_c_mount_hole_d = 2.4;
usb_c_mount_pilot_d = pi_standoff_pilot_d;

usb_c_recess_fudge = 0.25;
usb_c_clearance_from_walls = 10.0;

usb_c_panel_x =
    case_w - wall - usb_c_clearance_from_walls - usb_c_panel_w;
usb_c_panel_y = wall + usb_c_clearance_from_walls;
usb_c_panel_center_x = usb_c_panel_x + usb_c_panel_w / 2;
usb_c_panel_center_y = usb_c_panel_y + usb_c_panel_h / 2;
usb_c_panel_z = 0;

usb_c_hole_centers = [
    [usb_c_panel_center_x - usb_c_hole_span / 2, usb_c_panel_center_y],
    [usb_c_panel_center_x + usb_c_hole_span / 2, usb_c_panel_center_y]
];

usb_c_support_rail_w = 1.4;
usb_c_support_rail_h = 5.0;
usb_c_support_end_w = 1.4;

usb_c_connector_preview_w = usb_c_header_cutout_w;
usb_c_connector_preview_d = usb_c_header_cutout_h;
usb_c_connector_preview_h = 6.0;

// -----------------------------------------------------------------------------
// Markings and rubber feet
// -----------------------------------------------------------------------------

base_part_number = "mK-piclock v2.32r";
base_part_number_size = 4.0;
base_part_number_h = 0.45;
base_part_number_x = pi_x + pi_w / 2;
base_part_number_y = pi_y + pi_h / 2;

// Raised on the lid underside, below the OLED PCB footprint.
// Mirrored so it reads correctly when viewing the removed lid from inside.
lid_part_number = "MK-PiClock-V2.3R";
lid_part_number_size = 3.4;
lid_part_number_h = 0.55;
lid_text_overlap = 0.05;
lid_part_number_x = case_w / 2;
lid_part_number_y = 11.0;

// Lid orientation marks, raised on the underside and clear of the OLED PCB.
lid_orientation_text_size = 3.6;
lid_orientation_text_h = 0.55;
lid_top_text_x = case_w / 2;
lid_top_clear_edge_y = case_h - (wall + lip_clearance + lip_wall);
lid_top_text_y = (oled_y + oled_pcb_h + lid_top_clear_edge_y) / 2;

usb_c_polarity_mark_size = 4.0;
usb_c_polarity_mark_h = 0.45;
usb_c_polarity_mark_y = usb_c_panel_y - 4.0;
usb_c_polarity_plus_x =
    usb_c_panel_center_x - usb_c_hole_span / 2;

rubber_foot_size = 22;
rubber_foot_recess_depth = 1.2;
rubber_foot_x_margin = 8;
rubber_foot_z_margin = 2;

rubber_foot_x_positions = [
    rubber_foot_x_margin,
    case_w - rubber_foot_x_margin - rubber_foot_size
];

rubber_foot_z_positions = [
    rubber_foot_z_margin,
    case_d - rubber_foot_z_margin - rubber_foot_size
];

// -----------------------------------------------------------------------------
// Touch sensor
// -----------------------------------------------------------------------------

touch_pcb_size = 24.0;
touch_pcb_t = 1.6;
touch_hole_span = 20.0;
touch_m25_clearance_d = 2.9;

touch_m25_head_d = 5.5;
touch_m25_head_h = 1.6;
touch_m25_head_seat_depth = 0.5;
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

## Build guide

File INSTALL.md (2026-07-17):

# mk-piclock v1.8.1: Build and Install

> A practical installation guide for the Raspberry Pi Zero W and Zero 2 W builds of mk-piclock Kids.

| Product | HTTP API | Private IPC |
|:--|:--|:--|
| `1.8.1` | `1.25` | `16` |

mk-piclock uses two native C services:

- `mk-piclock-core` controls the OLED, touch sensor, RGB LED, alarms, messages, and audio.
- `mk-piclock-api` provides the browser interface, uploads, media processing, backups, and diagnostics.

Install both services from the same release.

## Contents

- [Before you start](#before-you-start)
- [Supported platform](#supported-platform)
- [Prepare Raspberry Pi OS](#prepare-raspberry-pi-os)
- [Install build dependencies](#install-build-dependencies)
- [Configure the Raspberry Pi hardware](#configure-the-raspberry-pi-hardware)
- [Verify the hardware interfaces](#verify-the-hardware-interfaces)
- [Extract and verify the release](#extract-and-verify-the-release)
- [Build mk-piclock](#build-mk-piclock)
- [Install the services](#install-the-services)
- [Open the web interface](#open-the-web-interface)
- [Reset a lost password](#reset-a-lost-password)
- [Initial setup](#initial-setup)
- [Upgrade an existing clock](#upgrade-an-existing-clock)
- [Storage locations](#storage-locations)
- [Logs and service control](#logs-and-service-control)
- [Troubleshooting](#troubleshooting)

---

## Before you start

You will need:

- Raspberry Pi Zero W or Raspberry Pi Zero 2 W
- Raspberry Pi OS Lite based on Debian 13 Trixie
- SSD1322 256x64 OLED
- MAX98357A I2S amplifier
- 4-ohm, 3-watt speaker
- TTP223B touch sensor
- Common-cathode RGB LED with one resistor per colour channel
- MicroSD card
- Reliable 5 V power supply

> [!IMPORTANT]
> Review `pinouts.md` before applying power. Confirm every 3.3 V, 5 V, ground, GPIO, SPI, I2S, and LED connection.

### Power

Use a reliable **5 V, 2 A or better** power supply.

A **USB-A to USB-C cable** is recommended for the current enclosure power connection. The simple USB-C power board does not perform full USB-C current negotiation, so some USB-C to USB-C supplies may not provide power correctly.

Do not power the clock from the Raspberry Pi and an external 5 V input at the same time.

---

## Supported platform

### Operating system

```text
Raspberry Pi OS Lite
Debian 13 Trixie
```

The source uses the **libgpiod 2.x API**.

Confirm the operating system:

```bash
cat /etc/os-release
```

Confirm the Pi model:

```bash
tr -d '\0' </proc/device-tree/model
printf '\n'
```

### Build jobs

| Raspberry Pi | Build command |
|:--|:--|
| Zero W | `make -j1` |
| Zero 2 W | `make -j2` |

The project is intended for the Pi Zero and Zero 2 family. Pi 5 instructions are intentionally excluded.

---

## Prepare Raspberry Pi OS

The easiest setup is through Raspberry Pi Imager.

Before writing the microSD card, configure:

- hostname
- Wi-Fi network and password
- username and password
- SSH, when remote access is required
- timezone

For Calgary and Edmonton time:

```bash
sudo timedatectl set-timezone America/Edmonton
sudo timedatectl set-ntp true
```

Confirm time synchronization:

```bash
timedatectl status
timedatectl show -p NTPSynchronized
```

Expected values include:

```text
System clock synchronized: yes
NTP service: active
NTPSynchronized=yes
```

mk-piclock reads the Linux system clock. It does not contact an NTP server itself.

> [!NOTE]
> The clock has no built-in battery-backed real-time clock. Correct time after a power loss depends on Linux restoring time and reaching a network time source.

---

## Install build dependencies

Update the package list:

```bash
sudo apt update
```

Install the required build packages:

```bash
sudo apt install --no-install-recommends -y \
  build-essential \
  pkg-config \
  libgpiod-dev \
  libpng-dev \
  libfreetype-dev \
  libasound2-dev \
  libmpg123-dev \
  libmp3lame-dev \
  libmicrohttpd-dev \
  unzip
```

Confirm libgpiod 2.x:

```bash
pkg-config --modversion libgpiod
```

---

## Configure the Raspberry Pi hardware

Raspberry Pi OS Lite based on Debian 13 stores boot configuration in:

```text
/boot/firmware/config.txt
```

### 1. Back up the file

```bash
sudo cp /boot/firmware/config.txt \
  /boot/firmware/config.txt.mk-piclock-backup
```

### 2. Edit the file

```bash
sudo nano /boot/firmware/config.txt
```

Add these lines under the existing `[all]` section:

```ini
# mk-piclock hardware

# SSD1322 OLED on SPI0
dtparam=spi=on

# Disable the Pi analogue audio device
dtparam=audio=off

# MAX98357A I2S amplifier
dtoverlay=max98357a,no-sdmode

# Reduce memory reserved for legacy GPU functions
gpu_mem=16
```

> [!IMPORTANT]
> Do not add a second `[all]` heading. Each setting should appear only once.

No changes to `/boot/firmware/cmdline.txt` are required.

### 3. Reboot

```bash
sudo reboot
```

---

## Verify the hardware interfaces

After rebooting, verify SPI and GPIO:

```bash
ls -l /dev/spidev0.0 /dev/gpiochip0
```

Verify that Linux created an ALSA sound card and playback device:

```bash
cat /proc/asound/cards
cat /proc/asound/pcm
```

The output should contain an I2S playback device. The exact card name can vary with the Raspberry Pi OS kernel.

### Expected GPIO assignments

| Device | BCM GPIO | Physical pin |
|:--|--:|--:|
| OLED SPI clock | GPIO11 | 23 |
| OLED SPI data | GPIO10 | 19 |
| OLED chip select | GPIO8 | 24 |
| OLED D/C | GPIO25 | 22 |
| OLED reset | GPIO27 | 13 |
| Touch sensor output | GPIO20 | 38 |
| RGB LED red | GPIO5 | 29 |
| RGB LED green | GPIO6 | 31 |
| RGB LED blue | GPIO13 | 33 |

See `pinouts.md` for the complete power, OLED, amplifier, speaker, touch, and RGB LED wiring table.

---

## Extract and verify the release

Place the release ZIP and `.sha256` file in the same directory.

For this v1.8.1 package:

```bash
cd ~
sha256sum -c mk-piclock-v1.8.1-production-final.zip.sha256
rm -rf mk-piclock-v1.8.1-production-final
unzip mk-piclock-v1.8.1-production-final.zip
cd mk-piclock-v1.8.1-production-final
```

A successful checksum test reports:

```text
mk-piclock-v1.8.1-production-final.zip: OK
```

When installing a differently named package, replace the filenames and directory name in the commands above.

---

## Build mk-piclock

### Raspberry Pi Zero W

```bash
make clean
make -j1
```

### Raspberry Pi Zero 2 W

```bash
make clean
make -j2
```

Confirm both programs were created:

```bash
ls -lh mk-piclock-core mk-piclock-api
```

Do not continue if either binary is missing.

---

## Install the services

Run:

```bash
make install
sudo systemctl restart \
  mk-piclock-core.service \
  mk-piclock-api.service
```

> [!IMPORTANT]
> Do not run `sudo make install`. The Makefile uses `sudo` only for the steps that require it.

The installer:

- creates restricted service accounts
- grants the core access to audio, SPI, and GPIO
- installs both binaries under `/opt/mk-piclock`
- installs the default alarm and message chime
- installs the complete web interface and OpenAPI document
- installs and enables both systemd services
- preserves existing configuration and uploaded media during upgrades

Confirm both services are running:

```bash
sudo systemctl --no-pager --full status \
  mk-piclock-core.service \
  mk-piclock-api.service
```

Both should show:

```text
Active: active (running)
```

---

## Open the web interface

### Find the clock address from the OLED

Simply hold down the touch sensor. The OLED network diagnostics screen shows:

- Wi-Fi network name
- Wi-Fi signal strength
- IP address
- hostname

Tap the sensor to close the screen. It also closes automatically.

### Find the address from Linux

```bash
hostname -I
```

Open the clock in a browser:

```text
http://<clock-ip>:8080/
```

Example:

```text
http://192.168.1.42:8080/
```

### Password behaviour

- When no password is configured, the controls open directly.
- When a password exists, the browser asks for it before opening the controls.
- Set, change, or remove the password under **System**.

The password is intentionally simple and stored as plain text on the clock. Keep port `8080` on a trusted home network. Do not expose it to the internet.

---

## Reset a lost password

A lost web password can be cleared from an SSH session or a local Linux terminal on the Raspberry Pi. You must still know the Raspberry Pi Linux account password to use `sudo`.

The OLED network diagnostics screen can show the clock IP address when needed. Simply hold down the touch sensor to open it.

### 1. Connect to the clock

From another computer:

```bash
ssh <linux-user>@<clock-ip>
```

Replace `<linux-user>` with the Raspberry Pi OS username and `<clock-ip>` with the address shown on the OLED.

### 2. Stop the web service

```bash
sudo systemctl stop mk-piclock-api.service
```

### 3. Remove the saved web password

```bash
sudo rm -f \
  /opt/mk-piclock/config/web-password.txt \
  /opt/mk-piclock/config/.web-password.tmp
```

### 4. Start the web service

```bash
sudo systemctl start mk-piclock-api.service
sudo systemctl --no-pager --full status mk-piclock-api.service
```

The service should report `Active: active (running)`.

### 5. Open the web interface

Reload:

```text
http://<clock-ip>:8080/
```

The password prompt will no longer appear. Open **System** to set a new password, or leave it blank to keep password protection disabled.

> [!IMPORTANT]
> This resets only the mk-piclock web password. It does not change the Raspberry Pi Linux login and does not remove alarms, settings, images, music, stories, or backups.

---

## Initial setup

Complete the following in the web interface:

1. Open **Display** and set the clock name, time format, font, brightness, and bedtime schedule.
2. Choose the browser preview colour that matches the physical OLED panel.
3. Upload normal artwork under **Day Images**.
4. Upload night artwork under **Bedtime Images**.
5. Upload songs under **Music**.
6. Upload story MP3 files under **Stories**.
7. Configure the alarm slots.
8. Configure Story Mode and its intro text.
9. Open **Lighting**, select the six activity profiles, and test the RGB LED channels.
10. Open **System** and confirm network, NTP, storage, OLED, touch, and service health.
11. Set an optional web password under **System**.
12. Download an initial backup.

### Messages

Each OLED message can optionally play the built-in short chime when it appears. The chime is skipped when other audio is already playing.

### Touch controls

- Tap while an alarm is active to dismiss it.
- Tap while music or a story is playing to stop it.
- Hold, then release, to play a random song.
- Keep holding to open network diagnostics.
- Tap ten times within the Story Mode window to play a random story when Story Mode is enabled.

The diagnostic hold does not start music and is not counted toward Story Mode.

### Browser confirmations

Save, test, upload, delete, and other confirmations appear in a floating notice. The result remains visible even when the page is scrolled.

---

## Upgrade an existing clock

Installing a new release replaces the programs, web interface, service files, default alarm, message chime, and API document.

It does not intentionally remove:

- clock configuration
- alarm settings
- uploaded images
- uploaded music
- uploaded stories
- uploaded fonts
- RGB lighting settings
- optional web password

### Recommended upgrade steps

```bash
cd ~/mk-piclock-v1.8.1-production-final
make clean
make -j2
make install
sudo systemctl restart \
  mk-piclock-core.service \
  mk-piclock-api.service
```

Use `make -j1` on a Pi Zero W.

Confirm the installed versions under **System**:

```text
Product:     1.8.1
HTTP API:    1.25
Private IPC: 16
```

The core, API, and browser interface must come from the same release.

When the browser reports an API version mismatch:

1. Rebuild the release.
2. Run `make install` again.
3. Restart both services.
4. Hard-refresh the browser.

### Backup before a major change

Use **System > Download Backup** before large upgrades or configuration changes.

Uploaded music and stories are excluded from the built-in backup and should be copied separately when required:

```bash
sudo cp -a /opt/mk-piclock/assets/music ~/mk-piclock-music-backup
sudo cp -a /opt/mk-piclock/assets/stories ~/mk-piclock-stories-backup
```

---

## Storage locations

| Purpose | Path |
|:--|:--|
| Core binary | `/opt/mk-piclock/mk-piclock-core` |
| API binary | `/opt/mk-piclock/mk-piclock-api` |
| Day Images | `/opt/mk-piclock/assets/images` |
| Bedtime Images | `/opt/mk-piclock/assets/bedtime-images` |
| Music | `/opt/mk-piclock/assets/music` |
| Music processing | `/opt/mk-piclock/assets/music/.processing` |
| Stories | `/opt/mk-piclock/assets/stories` |
| Fonts | `/opt/mk-piclock/assets/fonts` |
| Default alarm | `/opt/mk-piclock/assets/default-alarm.mp3` |
| Message chime | `/opt/mk-piclock/assets/message-chime.mp3` |
| Clock configuration | `/opt/mk-piclock/config/clock.conf` |
| Optional web password | `/opt/mk-piclock/config/web-password.txt` |
| Event log | `/opt/mk-piclock/config/event.log` |
| Web interface | `/opt/mk-piclock/web` |
| OpenAPI document | `/opt/mk-piclock/api/openapi-v1.json` |
| Private core socket | `/run/mk-piclock/core.sock` |

Old `auth`, `faces`, `bedtime-faces`, and `bedtime_faces` directories are not used.

---

## Logs and service control

### View service status

```bash
sudo systemctl status mk-piclock-core.service
sudo systemctl status mk-piclock-api.service
```

### Restart both services

```bash
sudo systemctl restart \
  mk-piclock-core.service \
  mk-piclock-api.service
```

### Recent core log

```bash
sudo journalctl -b \
  -u mk-piclock-core.service \
  -n 100 \
  --no-pager
```

### Recent API log

```bash
sudo journalctl -b \
  -u mk-piclock-api.service \
  -n 100 \
  --no-pager
```

### Follow both logs

```bash
sudo journalctl -f \
  -u mk-piclock-core.service \
  -u mk-piclock-api.service
```

---

## Troubleshooting

### Web interface does not open

Confirm the API is running:

```bash
sudo systemctl restart mk-piclock-core mk-piclock-api
sudo systemctl --no-pager --full status mk-piclock-api
sudo journalctl -b -u mk-piclock-api -n 100 --no-pager
```

Confirm the clock IP:

```bash
hostname -I
```

Port `8080` must be reachable from the local network.

### Forgotten web password

Follow [Reset a lost password](#reset-a-lost-password). The recovery removes only the optional web password file and leaves the clock configuration and media intact.

### API version mismatch

Reinstall the complete release, not only one binary:

```bash
make clean
make -j2
make install
sudo systemctl restart mk-piclock-core mk-piclock-api
```

Use `make -j1` on a Pi Zero W, then hard-refresh the browser.

### OLED is blank

```bash
ls -l /dev/spidev0.0 /dev/gpiochip0
id mk-piclock-core
sudo journalctl -b -u mk-piclock-core -n 100 --no-pager
```

Confirm:

- SPI is enabled
- OLED wiring matches `pinouts.md`
- OLED power is 3.3 V where specified
- D/C, reset, and chip-select pins are correct
- `mk-piclock-core` belongs to the `spi` and `gpio` groups

### No sound

Check the kernel ALSA devices and the core service log:

```bash
cat /proc/asound/cards
cat /proc/asound/pcm
id mk-piclock-core
sudo journalctl -b -u mk-piclock-core.service -n 100 --no-pager
```

Confirm:

- `dtoverlay=max98357a,no-sdmode` is active
- the amplifier is connected to the Pi I2S pins
- the speaker is connected to the amplifier output
- the amplifier SD/EN connection is not holding the board disabled
- `mk-piclock-core` belongs to the `audio` group

### Touch does not respond

Confirm the TTP223B output is connected to BCM GPIO20, physical pin 38.

Follow the core log while touching the sensor:

```bash
sudo journalctl -f -u mk-piclock-core.service
```

### Network diagnostics shows unavailable values

The OLED and System diagnostics read values exposed by the Linux network driver. SSID or signal fields can show unavailable when the interface is disconnected or the driver does not expose the value.

### Wrong time after startup

```bash
sudo timedatectl set-timezone America/Edmonton
sudo timedatectl set-ntp true
timedatectl status
```

Allow the Pi to connect to Wi-Fi and synchronize.

### Build header is missing

Install the matching development package, then rebuild:

```bash
make clean
make -j2
```

Common packages are:

- `libmicrohttpd-dev`
- `libgpiod-dev`
- `libasound2-dev`
- `libmpg123-dev`
- `libmp3lame-dev`
- `libfreetype-dev`
- `libpng-dev`

### Re-add existing image assets

The recommended method is uploading the original PNG files through **Day Images** and **Bedtime Images**. The API creates the matching OLED `.raw` files.

Existing converted artwork works only when both files share the same base name:

```text
example.png
example.raw
```

After copying files manually, restore ownership and restart the services:

```bash
sudo chown -R mk-piclock-api:mk-piclock /opt/mk-piclock/assets
sudo chmod -R u=rwX,g=rX,o= /opt/mk-piclock/assets
sudo systemctl restart mk-piclock-core mk-piclock-api
```

A PNG without its converted `.raw` partner does not appear in the OLED image rotation.

---

## Related documentation

| Document | Purpose |
|:--|:--|
| `README.md` | Features and normal use |
| `pinouts.md` | Complete hardware wiring |
| `CHANGELOG.md` | Version history |
| `RELEASE_NOTES.md` | Current release changes |
| `ADDON_API.md` | HTTP API details |
| `api/openapi-v1.json` | OpenAPI schema |

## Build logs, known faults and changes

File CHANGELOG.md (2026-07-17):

## v1.8.1 - 2026-07-17

### GUI consistency polish

- Standardized every GUI card heading with the same divider, spacing, and title alignment.
- Changed inactive sound status from `Quiet` to `None` across the GUI.
- Added consistent spacing between RGB Lighting and Global Controls.
- Removed the duplicate divider beneath the Web password description.
- Added matching headings to Story playback and Activity history.
- Updated browser asset identifiers to prevent stale cached files.
- Kept HTTP API at 1.25 and private IPC at 16.

## v1.8.0 - 2026-07-17

### Production display and code cleanup

- Removed the obsolete OLED Wi-Fi and alarm pill renderer, geometry helpers, and icon routines.
- Replaced the old footer with `W.xxx | ALARM ON`; disconnected Wi-Fi now shows a blinking `W.OFF`.
- Right-aligned the time and date to the same fixed display edge.
- Restored the permanent one-pixel separator with a moving black seconds position.
- Changed footer Wi-Fi detection to require carrier and IPv4, with a one-second cache instead of 60 seconds.
- Removed the redundant `trim_ascii_line()` and `read_first_line_from_file()` helpers.
- Added `-Werror=unused-function` and `-Werror=implicit-function-declaration` to both native builds.
- Removed the unnecessary `gpiod` command-line package from the documented dependency list.
- Audited all C translation units and browser modules; no other unreferenced functions were found.
- Kept HTTP API at 1.25 and private IPC at 16.

## v1.7.6 - 2026-07-10

### Clean OLED network diagnostics

- Removed unsupported parentheses from the OLED Wi-Fi signal line.
- Changed the signal display from `75% (-62 dBm)` to `75% -62 dBm` so every character exists in the built-in 5x7 font.
- Simplified README instructions to say that holding the touch sensor opens network diagnostics, without exposing the internal threshold.
- Kept the music, diagnostics, and Story Mode gesture logic unchanged.
- Kept HTTP API at 1.25 and private IPC at 16.

## v1.7.5 - 2026-07-10

### Safer diagnostics gesture and complete feature documentation

- Increased the OLED network diagnostic hold from six seconds to eight seconds.
- Kept random music on release after a three-second hold, provided the sensor is released before diagnostics opens.
- Kept diagnostic holds separate from the 10-tap Story Mode gesture.
- Expanded README coverage for the optional password, message chime, OLED diagnostics, floating GUI confirmations, and OLED metadata filtering.
- Kept HTTP API at 1.25 and private IPC at 16.

## v1.7.4 - 2026-07-10

### Clean OLED song metadata

- Filtered song titles and artists against the exact built-in 5x7 OLED glyph set.
- Omitted unsupported Unicode, emoji, symbols, and malformed characters instead of rendering fallback question marks.
- Filtered title and artist separately before assembling the OLED display line.
- Collapsed repeated spaces and removed leading or trailing spaces.
- Preserved the original metadata for the status API and web GUI.
- Kept HTTP API at 1.25 and private IPC at 16.

## v1.7.3 - 2026-07-10

### Optional password, message chime, OLED diagnostics, and floating confirmations

- Added a simple optional plaintext password for the web GUI and API.
- Added conditional login, session-cookie handling, and password controls on System.
- Added an optional built-in chime for immediate, delayed, and scheduled messages.
- Added a six-second touch hold for an OLED network diagnostic screen showing SSID, signal, IP address, and hostname.
- Changed the three-second music gesture to start on release so a six-second hold cannot trigger music first.
- Kept the diagnostic gesture separate from the 10-tap Story Mode gesture.
- Changed browser acknowledgments to a fixed floating notice visible from any scroll position.
- Increased HTTP API to 1.25 and private IPC to 16.

## v1.7.2 - 2026-07-07

### Story Mode intro display fix

- Kept the Story Mode intro splash visible for its full startup window even if the audio thread exits quickly.
- Added `story_intro_active` to `/api/v1/status` so the web GUI can report the intro state directly.
- Updated the Stories and Dashboard pages to show the configured intro message during startup instead of briefly flashing generic status text.
- Kept HTTP API at 1.24 and private IPC at 15.

## v1.7.1 - 2026-07-07

### MP3 queue cleanup

- Replaced the per-file queue loop with the cleaner atomic batch queue.
- Validated and staged the full MP3 selection before queueing any jobs.
- Rolled back staged source files if the batch cannot be queued.
- Kept upload blocking while any music job is queued or processing.
- Added selected-song count and total-size feedback on the Music page.
- Kept HTTP API at 1.24 and private IPC at 15.

## v1.7.0 - 2026-07-07

### Touch lighting and batch music uploads

- Added a high-priority touch lighting scene so pressing the TTP223B sensor blinks the RGB LED.
- Added Global Lighting controls for touch blink enable, colour, and brightness. Default is a white blink.
- Allowed one MP3 upload request to contain a batch of files.
- Kept new MP3 uploads blocked until all queued and processing music jobs are complete.
- Audited installer and runtime directory creation; no obsolete or unused directories are created.
- Increased HTTP API to 1.24 and kept private IPC at 15.

## v1.6.57 - 2026-07-05

### RGB lighting stability

- Replaced leading-edge PWM with trailing-edge PWM so late low-brightness pulses are skipped rather than stretched.
- Removed temporal dithering that caused visible low-level brightness modulation.
- Added stable 32-level output quantization.
- Added modest real-time scheduling for only the LED timing thread through `LimitRTPRIO`.
- Kept the HTTP API at 1.23 and private IPC at 15.

## v1.6.56 - 2026-07-05

### RGB lighting reliability and control

- Fixed the LED scene race between the control thread and renderer.
- Added batched GPIO writes, error counting, and automatic shutdown after repeated write failures.
- Added 200 Hz, 32-level PWM with temporal dithering and zero-output sleeping.
- Added linear-light fades, calibrated RGB gains, and 350 ms scene crossfades.
- Added a master switch, global brightness ceiling, idle-off mode, and gradual bedtime dimming.
- Added configurable effect-cycle timing, per-profile reset controls, and RGB wiring tests.
- Split intended LED colour from calibrated output in status and diagnostics.
- Revised bedroom defaults to reduce glare.
- Increased HTTP API to 1.23 and private IPC to 15.

## v1.6.55 - 2026-06-28

### RGB activity lighting

- Added six persistent LED profiles for Alarm, Bedtime, Message, Music, Daytime, and Stories.
- Added solid colour, two-colour fade, rainbow, and 0% to 100% brightness controls.
- Added common-cathode software PWM on GPIO5, GPIO6, and GPIO13.
- Added a Lighting GUI page with ten-second hardware previews.
- Connected Stories lighting to the existing `story_playing` runtime state.
- Added strict activity priority: Alarm, Message, Stories, Music, Bedtime, Daytime.
- Prevented previews from overriding an active alarm.
- Added LED status and profile data to `/api/v1/status`.
- Added `/api/v1/config/led` and `/api/v1/led/preview`.
- Increased HTTP API to 1.22 and private IPC to 14.

## v1.6.54 - 2026-06-24

### Dead-code cleanup

- Removed the obsolete `include_music` rollback switch and its restore compatibility branches.
- Replaced mixed restore/reset flags with explicit Restore and Factory Reset asset sets.
- Removed discarded ZIP entry-count outputs from image downloads and full backups.
- Removed the duplicate image-library ZIP central-directory writer and reused the shared ZIP finalizer.
- Removed the generic restore parent-directory parser; restore staging now creates only the known supported directories.
- Replaced the remaining recursive `PATH_MAX` cleanup routine with descriptor-based `openat()` and `unlinkat()` traversal.
- Consolidated flat asset move, clear, rollback, and staging logic.
- Kept HTTP API 1.21 and private IPC 13 unchanged.

## v1.6.53 - 2026-06-24

### API and backup hardening

- Replaced recursive `PATH_MAX` stack buffers with descriptor-based traversal using `openat()`, `fdopendir()`, and `fstatat()`.
- Kept the 32-level directory guard while reducing per-level stack use and refusing symlink traversal.
- Replaced the bit-at-a-time CRC32 loop with a thread-safe table implementation.
- Kept CRC32 portable across Raspberry Pi Zero, Zero 2 W, and Pi 5 builds instead of requiring ARMv8 CRC instructions.
- Changed ZIP DOS timestamps to UTC for deterministic backup metadata across timezone and daylight-saving changes.
- Added explicit `INT_MIN` and `INT_MAX` validation before converting parsed JSON integers to `int`.
- Kept HTTP API 1.21 and private IPC 13 unchanged.

## v1.6.52 - 2026-06-24

- Ignored all touch-sensor input during the Story Mode intro and title sequence.
- Cleared the ten-tap counter while touch input was locked.
- Hid the Wi-Fi and alarm status pills for the full duration of story playback.
- Restored the pills automatically when the story stopped or finished.
- Kept the normal Wi-Fi and alarm pill design unchanged outside Story Mode.

## v1.6.51 - 2026-06-24

- Removed the unused `collect_music_files()` helper that caused `-Wunused-function`.
- Folded the single-use audio-directory collector into the shared playable-library selector.
- Removed the unused `story_mode` field from the playback-thread request structure.
- Kept Story Mode behaviour, HTTP API 1.21, and private IPC 13 unchanged.

## v1.6.50 - 2026-06-24

- Added Story Mode with a separate Stories MP3 library.
- Added a ten-tap touch gesture completed within eight seconds.
- Added an independent story volume and parent enable switch.
- Added a configurable `STORY MODE!` OLED intro message.
- Added a random Bedtime Images collage for each story start.
- Added a timed story title display before the OLED returns to the normal clock.
- Added story upload, list, play, stop, delete, and delete-all API routes.
- Added story storage size and file count to System diagnostics.
- Excluded stories from backup and restore.
- Increased the HTTP API to 1.21 and private IPC to 13.

## v1.6.49 - 2026-06-24

### Build correction

- Removed the GCC `-Wformat-truncation` warning in Inventory ID generation.
- Replaced the variable `%s` write with an explicit bounded copy.
- Preserved the Inventory ID format and device-identity behaviour.
- Kept HTTP API version 1.20 because the API schema is unchanged.

## v1.6.48 - 2026-06-24

### Device identity

- Added a short Inventory ID derived from the Raspberry Pi board serial.
- Added the full Raspberry Pi serial to the System page, diagnostics API, and downloadable report.
- Added Raspberry Pi board revision and the operating-system machine ID.
- Added a CPU signature for processor identification and marked it as non-unique.
- Increased the HTTP API version to 1.20.

## v1.6.47 - 2026-06-24

### System identification

- Added the installed release version to the System page.
- Added the HTTP API version and API compile date and time.
- Added the same build information to the downloadable diagnostic report.

### Storage usage

- Split root filesystem storage into used, available, and total values.
- Added percentage used to the System page.
- Added directory sizes and file counts for Day Images, Bedtime Images, music, and fonts.
- Kept storage inspection in-process without external commands.

## v1.6.46 - 2026-06-24

- Corrected the earlier sidebar interpretation.
- Removed the blue vertical active-item bar from the desktop left navigation.
- Kept the active item background and text colour.
- Restored the standard pointer cursor for sidebar links.
- Left the clock-name hover behaviour unchanged.

# mk-piclock Changelog

This file records user-visible changes to the native C release.

## v1.6.45 - 2026-06-24

### Backup scope cleanup

- Removed all music-entry handling from restore.
- Removed the unused music-file allowance from backup creation.
- Backup and restore now contain no music processing, validation, extraction, or staging logic.
- Backups remain limited to configuration, Day Images, Bedtime Images, and fonts.

## v1.6.43 - 2026-06-24

### Backup scope

- Removed uploaded music from backup ZIP files.
- Left the existing music library untouched during restore.
- Allowed restore while music is queued or processing because restore does not touch music.
- Kept factory reset behaviour unchanged, including deletion of uploaded music.

### Header cleanup

- Removed the clock-name hover hint. This was reverted in v1.6.45.
- Replaced the text-selection cursor over the clock name with the normal cursor.
- Prevented accidental selection of the header clock name.

## v1.6.42 - 2026-06-24

### Build correction

- Removed the GCC `-Wformat-truncation` warning in storage device-path resolution.
- Added an explicit destination-size check before constructing `/dev/<device>`.
- Preserved the command-free runtime and existing diagnostic behaviour.

## v1.6.41 - 2026-06-24

### Network diagnostics

- Replaced `getifaddrs()` with direct IPv4 interface ioctls so network diagnostics work inside the restricted API service.
- Added default-route interface selection and a wireless-interface fallback.
- Corrected zero-percent Wi-Fi signal handling so a weak connection is not mistaken for missing data.
- Kept diagnostics command-free and retained the existing restricted address-family sandbox.

### Platform and storage diagnostics

- Added Raspberry Pi model, operating system, OS release, codename, kernel, architecture, and uptime.
- Added system drive, root partition, filesystem, read-only state, boot partition, boot filesystem, and boot mount point.
- Added inserted SD-card device, type, product name, capacity, manufacturer ID, OEM ID, serial, manufacture date, and CID.
- Expanded the downloadable diagnostic report with the same platform and storage details.
- Updated HTTP API to 1.18. Private IPC remains 12.

## v1.6.40 - 2026-06-24

### Alarm safety

- Changed alarms to loop until dismissed with the physical touch sensor.
- Rejected browser stop commands while an alarm is active.
- Added a protected built-in fallback MP3 for missing, unreadable, or invalid alarm music.
- Added a 30-minute maximum alarm duration.
- Recorded the last alarm that successfully started audio.
- Added next-alarm calculations and Home-page display.

### Bedtime controls

- Added a parent setting to disable manual music during bedtime.
- Blocked browser and touch-started music during the configured bedtime window.
- Stopped ordinary music automatically when bedtime begins.
- Kept scheduled alarms independent from the bedtime music restriction.

### System, backup, and diagnostics

- Added IP address, hostname, SSID, Wi-Fi signal, NTP state, CPU temperature, storage, API/core health, OLED health, and touch health.
- Added a Home-page time synchronization warning.
- Added a downloadable diagnostic report.
- Added complete backup download and validated restore.
- Added factory reset for settings and user-added assets.
- Protected reset and restore from active alarms and music processing.
- Updated HTTP API to 1.17 and private IPC to 12.

## v1.6.39 - 2026-06-23

### Complete static-asset cleanup

- Changed `make install` to stop the API before replacing web files.
- Replaced `/opt/mk-piclock/web` and `/opt/mk-piclock/api` as complete trees instead of deleting only visible children.
- Removed stale hidden files, retired modules, and superseded assets from prior installations.
- Changed every GUI resource, including icons and the favicon, to `Cache-Control: no-store`.
- Added v1.6.39 revision keys to the manifest, icons, module list, module HTML, CSS, and JavaScript.
- Removed the unused 48x48 favicon.
- Changed `make uninstall` to remove installed web and API documentation trees while preserving user images, music, fonts, and configuration.
- Kept HTTP API 1.16 and private IPC 11 unchanged.

## v1.6.38 - 2026-06-23

### GUI cache compatibility

- Fixed a false GUI/API mismatch where a cached v1.15 `app.js` rejected the running v1.16 API.
- Changed mutable GUI resources, including HTML, CSS, JavaScript, JSON, and manifests, to `Cache-Control: no-store`.
- Stopped returning `304 Not Modified` for no-store resources.
- Updated GUI asset revision URLs to v1.6.38 so browsers request the current files immediately after installation.
- Kept HTTP API 1.16 and private IPC 11 unchanged.

### Cause corrected

The GUI cache key had not changed when the required API moved from v1.15 to v1.16. The server also cached GUI files for one hour and generated ETags from file timestamp and size only. Because `1.15` and `1.16` have the same length, an old JavaScript file could remain valid in the browser even after the new API was installed.

## v1.6.37 - 2026-06-23

### Music queue reliability

- Limited MP3 upload to one file per request.
- Refused new uploads while any song is queued or processing.
- Added a browser-side queue check before upload.
- Added an atomic API-side busy check to prevent overlapping requests.
- Disabled upload controls while the worker is busy.
- Added **Clear Queue** for waiting uploads and their temporary source files.
- Kept the active transcode running when the waiting queue is cleared.
- Changed the processing view so the active job is listed before queued and completed jobs.
- Updated HTTP API to 1.16.

### Cause corrected

The previous uploader could start transcoding the first file while the same request was still validating and staging later files. It also accepted another upload while the worker was active. On a Raspberry Pi, this allowed concurrent MP3 decoding and heavy storage activity. Later items could remain displayed as **Queued**, while the older active item was hidden by the limited newest-first list.

## v1.6.36 - 2026-06-23

### Access-control cleanup

- Removed the final obsolete access-control path from the API systemd service.
- Removed old install and uninstall cleanup commands for the deleted auth directory.
- Removed historical access-control compatibility text from active documentation.
- Confirmed that no auth routes, auth source modules, password files, remembered-browser keys, or OpenAPI security definitions remained.
- Kept HTTP API 1.15 and private IPC 11 unchanged.

## v1.6.35 - 2026-06-23

### Direct local controls

- Removed the GUI login screen.
- Removed password requirements.
- Removed remembered-device handling.
- Removed browser session and local storage authentication state.
- Removed credential, lockout, recovery, and access-key logic.
- Removed all `/api/v1/auth/*` routes.
- Removed the Security page and sign-out controls.
- Removed `auth_store.c` and `auth_store.h`.
- Removed the `/opt/mk-piclock/auth` data directory.
- Made all GUI and API routes directly available on the trusted local network.
- Updated HTTP API to 1.15.

### Retained

- Restricted core and API system users
- Private Unix socket between services
- Day and Bedtime **Download All PNGs** actions
- Centered mK browser, Apple, Android, and GUI icons

## v1.6.34 - 2026-06-23

### Historical access-key fix

This release still contained the password system that was removed in v1.6.35.

- Corrected valid access keys being rejected immediately after login.
- Moved authentication evaluation until after libmicrohttpd request parsing.
- Retained stale-response protection.
- Simplified the old remembered-browser implementation.
- Added SSH password recovery instructions.
- Retained login throttling and PBKDF2-HMAC-SHA256 password storage.

### Image library downloads

- Added or retained **Download All Day PNGs**.
- Added or retained **Download All Bedtime PNGs**.
- Excluded converted OLED `.raw` files from download ZIPs.

### Icons

- Added centered mK favicon sizes.
- Added Apple touch and Android launcher icons.
- Used the centered mK artwork in the GUI header.

## Earlier v1.6 development - consolidated

The following work was completed throughout earlier v1.6 releases. Some intermediate builds were experimental and were replaced by later implementations.

### Native architecture

- Moved the clock to a native C core and native C HTTP API.
- Split hardware ownership from web and asset processing.
- Added private binary IPC over `/run/mk-piclock/core.sock`.
- Replaced legacy GPIO access with libgpiod 2.x.
- Added systemd services and restricted service accounts.
- Added service hardening and limited writable paths.

### OLED and clock rendering

- Added SSD1322 256x64 SPI support.
- Added chunked framebuffer writes for SPI transfer limits.
- Added a large centred clock, full date, and blinking colon.
- Added 12-hour and 24-hour modes.
- Added built-in and uploaded font selection.
- Added FreeType caching and grayscale gamma handling.
- Added Wi-Fi and alarm status indicators.
- Added rotating images beside the clock.
- Added separate day and bedtime image rotation.
- Added OLED panel colour selection for browser previews.
- Added live raw framebuffer display on the Home page.

### Alarms and audio

- Added seven configurable alarms.
- Added weekday schedules.
- Added specific or random wake-up music.
- Added per-alarm start and final volumes.
- Added song-length-based alarm volume ramping.
- Added MP3 playback with mpg123 and ALSA.
- Added global volume control.
- Added title and artist display.
- Added scrolling long metadata.
- Improved common accented Latin metadata handling.
- Added touch input: short press stops audio and a three-second hold plays random music.

### Messages

- Added immediate OLED messages.
- Added delayed messages.
- Added scheduled messages up to 30 days ahead.
- Added specific and random Day or Bedtime image selection.
- Added image-only messages.
- Added persistent pending-message state.
- Replaced approximate browser wrapping with core-rendered OLED previews.
- Centred message lines using actual rendered dimensions.

### Image libraries

- Separated Day Images and Bedtime Images.
- Added PNG validation and conversion to OLED raw assets.
- Added upload, review, pagination, individual deletion, and delete-all controls.
- Preserved original PNG files for browser display and download.
- Removed the older face-specific terminology from current storage paths and GUI labels.

### Music library

- Added MP3 validation and in-process LAME transcoding.
- Added a recommended mono profile for the MAX98357A and small speaker.
- Added processing progress and job history.
- Added music metadata inspection.
- Added play, stop, and delete controls.
- Reset alarms to Random when their selected file is deleted.

### Web GUI

- Reorganized controls around everyday tasks.
- Added Home, Alarms, Messages, Music, Day Images, Bedtime Images, Display, and Recent Activity pages.
- Added responsive phone and tablet layouts.
- Moved technical options into collapsed sections.
- Added API and GUI version compatibility checks.
- Added recent event-log viewing.
- Added network and uptime status.

### Installation and hardware documentation

- Standardized Raspberry Pi OS Lite Debian 13 Trixie instructions.
- Added SPI, MAX98357A, GPIO, OLED, touch, and power wiring documentation.
- Added `gpu_mem=16` configuration.
- Documented service verification and journal inspection.
- Documented image migration from older face directories.

## Compatibility table

| Product | HTTP API | Private IPC | Notes |
| --- | ---: | ---: | --- |
| 1.8.1 | 1.25 | 16 | GUI consistency polish |
| 1.8.0 | 1.25 | 16 | Production cleanup and warning prevention |
| 1.7.6 | 1.25 | 16 | Clean OLED network diagnostics |
| 1.7.5 | 1.25 | 16 | Eight-second diagnostics hold and complete README |
| 1.7.4 | 1.25 | 16 | OLED metadata glyph filtering |
| 1.7.3 | 1.25 | 16 | Optional password, message chime, OLED diagnostics, and floating notices |
| 1.7.2 | 1.24 | 15 | Story Mode intro display fix |
| 1.7.1 | 1.24 | 15 | Atomic batch MP3 queue cleanup |
| 1.7.0 | 1.24 | 15 | Touch lighting and batch MP3 uploads |
| 1.6.57 | 1.23 | 15 | Stable trailing-edge RGB PWM |
| 1.6.56 | 1.23 | 15 | Calibrated, hardened RGB lighting |
| 1.6.55 | 1.22 | 14 | Six-mode RGB activity lighting |
| 1.6.54 | 1.21 | 13 | Dead-code and restore-transaction cleanup |
| 1.6.53 | 1.21 | 13 | Embedded API and backup hardening |
| 1.6.51 | 1.21 | 13 | Story Mode cleanup and warning removal |
| 1.6.50 | 1.21 | 13 | Story Mode, separate story library, touch gesture, and OLED intro |
| 1.6.49 | 1.20 | 12 | Inventory ID warning correction |
| 1.6.48 | 1.20 | 12 | Raspberry Pi device identity |
| 1.6.47 | 1.19 | 12 | Release, build, storage, and asset usage diagnostics |
| 1.6.46 | 1.18 | 12 | Sidebar active-bar removal |
| 1.6.45 | 1.18 | 12 | Sidebar cursor correction |
| 1.6.44 | 1.18 | 12 | Backup and restore contain no music handling |
| 1.6.43 | 1.18 | 12 | Music-free backups and header hover cleanup |
| 1.6.42 | 1.18 | 12 | Storage path build-warning correction |
| 1.6.41 | 1.18 | 12 | Network, platform, and SD-card diagnostics |
| 1.6.40 | 1.17 | 12 | Alarm safety, backup, and system diagnostics |
| 1.6.39 | 1.16 | 11 | GUI cache and API compatibility fix |
| 1.6.37 | 1.16 | 11 | Single MP3 upload and queue busy enforcement |
| 1.6.36 | 1.15 | 11 | Final access-control cleanup |
| 1.6.35 | 1.15 | 11 | Password system removed |
| 1.6.34 | 1.14 | 11 | Last password-protected release |

Core, API, web assets, and OpenAPI schema should be installed from the same release.

### GUI consistency update

- Standardized card heading dividers across all modules.
- Replaced inactive `Quiet` labels with `None`.
- Corrected Lighting page spacing and the Web password double divider.

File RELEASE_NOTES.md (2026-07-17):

# mk-piclock v1.8.1 Release Notes

## GUI consistency polish

- Added a consistent divider beneath every GUI card heading.
- Changed inactive sound labels from `Quiet` to `None`.
- Standardized spacing between RGB Lighting and Global Controls.
- Removed the duplicate divider beneath the Web password description.
- Added matching headings to Story playback and Activity history.
- Refreshed browser asset identifiers to prevent stale cached CSS or modules.

## Production display and code cleanup

- Removed the obsolete OLED pill renderer, rounded-pill geometry, Wi-Fi icon, music-note icon, and alarm-volume pill plumbing.
- Restored the approved footer format: `W.xxx | ALARM ON`, with `W.OFF` blinking when `wlan0` is not connected.
- Right-aligned the time and date to a fixed two-pixel display margin.
- Restored the permanent one-pixel footer separator with a moving black seconds position.
- Changed footer network detection to require Wi-Fi carrier and an assigned IPv4 address, refreshed once per second.
- Removed the redundant `trim_ascii_line()` and `read_first_line_from_file()` helpers.
- Added build enforcement for unused static functions and implicit function declarations.
- Removed the unneeded `gpiod` command-line package. `libgpiod-dev` remains required.
- Audited all C translation units and browser modules. No other unreferenced functions were found.
- Kept HTTP API 1.25 and private IPC 16.

## Versions

```text
Product:     1.8.1
HTTP API:    1.25
Private IPC: 16
```

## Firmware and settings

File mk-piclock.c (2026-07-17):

/*
  mk-piclock.c

  Private Raspberry Pi alarm clock core daemon.

  Features:
    - SSD1322 256x64 OLED over /dev/spidev0.0
    - libgpiod GPIO for OLED DC/RST and TTP223B touch input
    - Private Unix socket control service for mk-piclock-api
    - MP3 playback using libmpg123 + ALSA PCM
    - Alarms, fonts, images, messages, bedtime dimming, touch input, and config

  Build both services with the supplied Makefile.
*/

#define _GNU_SOURCE

#include <ctype.h>
#include <errno.h>
#include <dirent.h>
#include <fcntl.h>
#include <arpa/inet.h>
#include <net/if.h>
#include <linux/wireless.h>
#include <linux/spi/spidev.h>
#include <poll.h>
#include <pwd.h>
#include <alsa/asoundlib.h>
#include <mpg123.h>
#include <pthread.h>
#include <signal.h>
#include <stdarg.h>
#include <stdint.h>
#include <stdio.h>
#include <stdlib.h>
#include <string.h>
#include <sys/ioctl.h>
#include <sys/socket.h>
#include <sys/stat.h>
#include <sys/types.h>
#include <sys/un.h>
#include <time.h>
#include <unistd.h>

#include <ft2build.h>
#include FT_FREETYPE_H

#include <gpiod.h>

#include "ipc_protocol.h"
#include "led_control.h"
#include "asset_format.h"
#include "util.h"

#define safe_str mp_safe_str
#define write_all mp_write_full

#define APP_NAME "mk-piclock-core"
#define APP_VERSION "1.8.1"

#define LED_PROFILE(fx, level, seconds, r1, g1, b1, r2, g2, b2) \
    { .effect = (fx), .brightness = (level), .cycle_seconds = (seconds), .reserved = 0, \
      .red1 = (r1), .green1 = (g1), .blue1 = (b1), \
      .red2 = (r2), .green2 = (g2), .blue2 = (b2) }
#define DEFAULT_CLOCK_NAME "Rylie"
#define STARTUP_GREETING_SECONDS 3
#define APP_ROOT "/opt/mk-piclock"
#define IMAGE_DIR APP_ROOT "/assets/images"
#define BEDTIME_IMAGE_DIR APP_ROOT "/assets/bedtime-images"
#define MUSIC_DIR APP_ROOT "/assets/music"
#define STORY_DIR APP_ROOT "/assets/stories"
#define DEFAULT_ALARM_PATH APP_ROOT "/assets/default-alarm.mp3"
#define DEFAULT_ALARM_LABEL "Built-in Alarm"
#define MESSAGE_CHIME_PATH APP_ROOT "/assets/message-chime.mp3"
#define MESSAGE_CHIME_LABEL "Message Chime"
#define MESSAGE_CHIME_VOLUME_MAX 55
#define ALARM_MAX_DURATION_SECONDS 1800
#define FONT_DIR APP_ROOT "/assets/fonts"
#define CONFIG_DIR APP_ROOT "/config"
#define CONFIG_FILE CONFIG_DIR "/clock.conf"
#define LOG_FILE CONFIG_DIR "/event.log"
#define LOG_MAX_BYTES 65536
#define LOG_KEEP_BYTES 32768
#define LOG_VIEW_LINES 200


#define OLED_SPI_DEV "/dev/spidev0.0"
#define OLED_W 256
#define OLED_H 64
#define OLED_ROW_BYTES (OLED_W / 2)
#define OLED_FB_BYTES ((OLED_W * OLED_H) / 2)
#define SPI_SPEED_HZ 4000000
#define SPI_CHUNK 4096

#define MESSAGE_TEXT_X 70
#define MESSAGE_TEXT_W (OLED_W - MESSAGE_TEXT_X - 4)
#define MESSAGE_MAX_LINES 3
#define MESSAGE_LINE_CHARS 64
#define MESSAGE_INPUT_MAX_CHARS 180
#define MESSAGE_FALLBACK_SCALE 2
#define MESSAGE_TTF_MIN_PX 12
#define MESSAGE_TTF_MAX_PX 18
#define MESSAGE_DEFAULT_DURATION_SECONDS 30
#define MESSAGE_DELAY_MAX_SECONDS 60


#define GPIO_CHIP "/dev/gpiochip0"
#define GPIO_DC 25
#define GPIO_RST 27
#define GPIO_TOUCH 20
#define TOUCH_POLL_MS 20u
#define TOUCH_DEBOUNCE_MS 50u
#define TOUCH_LONG_PRESS_MS 3000u
#define TOUCH_DIAGNOSTIC_PRESS_MS 8000u
#define DIAGNOSTIC_SCREEN_SECONDS 30u
#define DIAGNOSTIC_REFRESH_MS 2000u
#define STORY_PRESS_COUNT 10
#define STORY_PRESS_WINDOW_MS 8000u
#define STORY_MESSAGE_MAX 64
#define STORY_COLLAGE_MAX_IMAGES 5
#define STORY_COLLAGE_IMAGE_SIZE 48
#define STORY_INTRO_SECONDS 3u
#define STORY_TITLE_SECONDS 4u

#define MAX_ALARMS 7
#define MUSIC_FILE_MAX 256
#define IMAGE_FILE_MAX 128
#define CLOCK_IMAGE_CHANGE_MAX_SECONDS 300
#define BEDTIME_IMAGE_CHANGE_SECONDS 300
#define CLOCK_TIME_Y_OFFSET -7
#define CLOCK_IMAGE_Y_NUDGE -2
#define CLOCK_SIDE_WIDGET_SIZE 54
#define CLOCK_SIDE_WIDGET_X 4
#define CLOCK_FOOTER_H 11
#define CLOCK_FOOTER_TEXT_Y (OLED_H - 8)
#define CLOCK_RIGHT_X (OLED_W - 2)
#define CLOCK_SECONDS_LINE_Y (OLED_H - CLOCK_FOOTER_H - 1)
#define CLOCK_SECONDS_LINE_LEVEL 12
#define CLOCK_STATUS_TEXT_X 2
#define CLOCK_STATUS_TEXT_GAP 6
#define SONG_METADATA_TEXT_MAX (MP_ID3_TEXT_MAX * 2 + 4)
#define SONG_SCROLL_SPEED_PX_PER_SEC 18u
#define SONG_SCROLL_GAP_PX 24
#define SONG_SCROLL_FRAME_US 75000u


#define CORE_RUNTIME_DIR "/run/mk-piclock"
#define CORE_SOCKET_PATH CORE_RUNTIME_DIR "/core.sock"
#define ASSET_LIST_MAX_FILES 256
#define ASSET_LIST_NAME_MAX MUSIC_FILE_MAX

static volatile sig_atomic_t g_running = 1;
static time_t g_start_time = 0;
static pthread_mutex_t g_log_lock = PTHREAD_MUTEX_INITIALIZER;

struct rotating_image_state {
    char file[IMAGE_FILE_MAX];
    time_t next_change;
};

static struct rotating_image_state g_rotating_images[2];

struct story_collage_state {
    char files[STORY_COLLAGE_MAX_IMAGES][IMAGE_FILE_MAX];
    int count;
};

static struct story_collage_state g_story_collage;

struct image_raw_cache {
    char file[IMAGE_FILE_MAX];
    int bedtime;
    uint8_t raw[MP_IMAGE_RAW_BYTES];
    int valid;
    unsigned long generation;
};

static pthread_mutex_t g_image_raw_cache_lock = PTHREAD_MUTEX_INITIALIZER;
static struct image_raw_cache g_image_raw_cache = { .file = "", .bedtime = 0, .valid = 0, .generation = 0 };

struct alarm_slot {
    int enabled;
    int hour;
    int min;
    int weekdays;          /* bit 0 Sunday through bit 6 Saturday */
    int start_volume;      /* 0..100 */
    int end_volume;        /* 0..100 */
    int fired_yday;
    char music_file[MUSIC_FILE_MAX]; /* empty = random uploaded MP3 */
};

struct app_state {
    int display_mode;       /* 0 clock, 1 clear, 2 message, 3 diagnostics */
    int display_dirty;      /* set by API IPC thread; drawn by main OLED loop */
    int diagnostic_return_mode;
    time_t diagnostic_until;
    char message_image_file[IMAGE_FILE_MAX];
    int message_image_bedtime;
    time_t message_until;   /* unix time; 0 = no active message */
    char message_text[192];
    char pending_message_image_file[IMAGE_FILE_MAX];
    int pending_message_image_bedtime;
    int pending_message_notification_sound;
    char pending_message_text[192];
    time_t pending_message_at;
    int global_volume;
    int story_mode_enabled;
    int story_volume;
    char story_message[STORY_MESSAGE_MAX];
    int story_playing;
    uint64_t story_intro_until_ms;
    uint64_t story_title_until_ms;
    int bedtime_enabled;
    int bedtime_start_hour;
    int bedtime_start_min;
    int bedtime_end_hour;
    int bedtime_end_min;
    int bedtime_dim_percent;
    int bedtime_music_enabled;
    int oled_contrast_current;
    int oled_master_current;
    int oled_brightness_current;
    int brightness_preview_percent;
    time_t brightness_preview_until;
    int audio_playing;
    char audio_file[MUSIC_FILE_MAX];
    char audio_title[MP_ID3_TEXT_MAX];
    char audio_artist[MP_ID3_TEXT_MAX];
    char audio_display[SONG_METADATA_TEXT_MAX];
    uint64_t audio_scroll_started_ms;
    int show_song_metadata;
    int alarm_active;             /* 1 only while an alarm MP3 is currently playing */
    int alarm_volume_percent;     /* current alarm ramp volume, 0..100 */
    long long last_successful_alarm;
    struct alarm_slot alarms[MAX_ALARMS];
    struct mp_led_profile led_profiles[MP_LED_SCENE_COUNT];
    struct mp_led_global_settings led_settings;
    int led_bedtime_fade_active;
    int led_preview_scene;
    time_t led_preview_until;
    int led_preview_bypass_master;
    int led_preview_raw_output;
    struct mp_led_profile led_preview_profile;
    int oled_ok;
    char clock_name[64];
    int oled_font;         /* 0 seven, 1 seven thin, 2 pixel, 3 pixel bold */
    char oled_font_file[128]; /* uploaded .ttf/.otf filename, empty = built-in */
    int oled_font_size;    /* TrueType pixel size */
    int clock_24h_mode;    /* 0 = 12-hour, 1 = 24-hour */
    int oled_color;        /* GUI panel colour: yellow, green, or white */
    pthread_mutex_t lock;
};

static struct app_state g_state = {
    .display_mode = 0,
    .display_dirty = 1,
    .diagnostic_return_mode = 0,
    .diagnostic_until = 0,
    .message_image_file = "",
    .message_image_bedtime = 0,
    .message_until = 0,
    .message_text = "",
    .pending_message_image_file = "",
    .pending_message_image_bedtime = 0,
    .pending_message_notification_sound = 0,
    .pending_message_text = "",
    .pending_message_at = 0,
    .global_volume = 80,
    .story_mode_enabled = 0,
    .story_volume = 55,
    .story_message = "STORY MODE!",
    .story_playing = 0,
    .story_intro_until_ms = 0,
    .story_title_until_ms = 0,
    .bedtime_enabled = 0,
    .bedtime_start_hour = 21,
    .bedtime_start_min = 0,
    .bedtime_end_hour = 7,
    .bedtime_end_min = 0,
    .bedtime_dim_percent = 35,
    .bedtime_music_enabled = 1,
    .oled_contrast_current = -1,
    .oled_master_current = -1,
    .oled_brightness_current = -1,
    .brightness_preview_percent = -1,
    .brightness_preview_until = 0,
    .audio_playing = 0,
    .audio_file = "",
    .audio_title = "",
    .audio_artist = "",
    .audio_display = "",
    .audio_scroll_started_ms = 0,
    .show_song_metadata = 1,
    .alarm_active = 0,
    .alarm_volume_percent = 0,
    .last_successful_alarm = 0,
    .led_profiles = {
        [MP_LED_SCENE_ALARM] = LED_PROFILE(MP_LED_EFFECT_FADE, 70, 8, 255, 0, 0, 255, 160, 0),
        [MP_LED_SCENE_BEDTIME] = LED_PROFILE(MP_LED_EFFECT_SOLID, 3, 8, 255, 48, 0, 255, 48, 0),
        [MP_LED_SCENE_MESSAGE] = LED_PROFILE(MP_LED_EFFECT_FADE, 35, 8, 0, 150, 255, 255, 255, 255),
        [MP_LED_SCENE_MUSIC] = LED_PROFILE(MP_LED_EFFECT_RAINBOW, 40, 12, 255, 0, 0, 0, 0, 255),
        [MP_LED_SCENE_DAYTIME] = LED_PROFILE(MP_LED_EFFECT_SOLID, 5, 8, 255, 220, 160, 255, 220, 160),
        [MP_LED_SCENE_STORIES] = LED_PROFILE(MP_LED_EFFECT_FADE, 15, 8, 125, 45, 255, 0, 90, 255),
        [MP_LED_SCENE_TOUCH] = LED_PROFILE(MP_LED_EFFECT_FADE, 60, 2, 255, 255, 255, 0, 0, 0)
    },
    .led_settings = {1, 100, 100, 65, 80, 0, 15, 1, 60, 255, 255, 255},
    .led_bedtime_fade_active = 0,
    .led_preview_scene = -1,
    .led_preview_until = 0,
    .led_preview_bypass_master = 0,
    .led_preview_raw_output = 0,
    .led_preview_profile = {0},
    .oled_ok = 0,
    .clock_name = DEFAULT_CLOCK_NAME,
    .oled_font = 0,
    .oled_font_file = "",
    .oled_font_size = 48,
    .clock_24h_mode = 0,
    .oled_color = MP_OLED_COLOR_GREEN,
    .lock = PTHREAD_MUTEX_INITIALIZER
};

struct font_cache_state {
    pthread_mutex_t lock;
    FT_Library library;
    FT_Face face;
    char loaded_file[128];
    int loaded_size;
};

static struct font_cache_state g_font = {
    .lock = PTHREAD_MUTEX_INITIALIZER,
    .library = NULL,
    .face = NULL,
    .loaded_file = "",
    .loaded_size = 0
};

struct audio_player_state {
    pthread_mutex_t lock;
    pthread_cond_t stopped;
    int running;
    int stop_requested;
    int alarm_mode;
    int notification_mode;
    int timed_out;
    uint64_t alarm_deadline_ms;
    char file[MUSIC_FILE_MAX];
};

static struct audio_player_state g_audio = {
    .lock = PTHREAD_MUTEX_INITIALIZER,
    .stopped = PTHREAD_COND_INITIALIZER,
    .running = 0,
    .stop_requested = 0,
    .alarm_mode = 0,
    .notification_mode = 0,
    .timed_out = 0,
    .alarm_deadline_ms = 0,
    .file = ""
};


struct oled_dev {
    int spi_fd;
    struct gpiod_chip *chip;
    struct gpiod_line_request *gpio_req;
    uint8_t fb[OLED_FB_BYTES];
    uint8_t prev_fb[OLED_FB_BYTES];
    uint8_t preview_fb[OLED_FB_BYTES];
    pthread_mutex_t preview_lock;
    int prev_valid;
};

static struct oled_dev g_oled = {
    .spi_fd = -1,
    .chip = NULL,
    .gpio_req = NULL,
    .preview_lock = PTHREAD_MUTEX_INITIALIZER,
    .prev_valid = 0
};

/* Drawing normally targets the physical OLED framebuffer. The message editor
 * can render into a thread-local scratch framebuffer so its browser preview is
 * produced by the exact same renderer without changing the physical screen. */
static _Thread_local uint8_t *g_oled_render_fb = NULL;

static uint8_t *oled_draw_fb(void) {
    return g_oled_render_fb ? g_oled_render_fb : g_oled.fb;
}

struct touch_dev {
    struct gpiod_chip *chip;
    struct gpiod_line_request *request;
    pthread_mutex_t lock;
    int ready;
    int pressed;
};

static struct touch_dev g_touch = {
    .chip = NULL,
    .request = NULL,
    .lock = PTHREAD_MUTEX_INITIALIZER,
    .ready = 0,
    .pressed = 0
};

static void touch_get_state(int *ready, int *pressed);

static void on_signal(int sig) {
    (void)sig;
    g_running = 0;
}

static int ensure_dir(const char *path) {
    char tmp[512];
    snprintf(tmp, sizeof(tmp), "%s", path);
    size_t len = strlen(tmp);
    if (len == 0) return -1;
    if (tmp[len - 1] == '/') tmp[len - 1] = '\0';

    for (char *p = tmp + 1; *p; p++) {
        if (*p == '/') {
            *p = '\0';
            mkdir(tmp, 0755);
            *p = '/';
        }
    }
    if (mkdir(tmp, 0755) != 0 && errno != EEXIST) return -1;
    return 0;
}

static int hex_value(char ch) {
    if (ch >= '0' && ch <= '9') return ch - '0';
    if (ch >= 'a' && ch <= 'f') return ch - 'a' + 10;
    if (ch >= 'A' && ch <= 'F') return ch - 'A' + 10;
    return -1;
}

static void config_encode_to_buffer(char *out, size_t out_len, const char *in) {
    static const char hex[] = "0123456789ABCDEF";
    if (!out || out_len == 0) return;
    out[0] = '\0';
    if (!in) in = "";

    size_t j = 0;
    for (const unsigned char *p = (const unsigned char *)in; *p && j + 1 < out_len; p++) {
        unsigned char ch = *p;
        int plain = isalnum(ch) || ch == '.' || ch == '_' || ch == '-';
        if (plain) {
            out[j++] = (char)ch;
        } else {
            if (j + 3 >= out_len) break;
            out[j++] = '%';
            out[j++] = hex[(ch >> 4) & 0x0F];
            out[j++] = hex[ch & 0x0F];
        }
    }
    out[j] = '\0';
}

static void config_decode_inplace(char *s) {
    if (!s) return;
    char *o = s;
    for (char *p = s; *p; p++) {
        if (*p == '%' && p[1] && p[2]) {
            int hi = hex_value(p[1]);
            int lo = hex_value(p[2]);
            if (hi >= 0 && lo >= 0) {
                *o++ = (char)((hi << 4) | lo);
                p += 2;
                continue;
            }
        }
        *o++ = *p;
    }
    *o = '\0';
}
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
int main(void) {
    g_start_time = time(NULL);

    if (mpg123_init() != MPG123_OK) {
        fprintf(stderr, "mpg123_init failed\n");
        return 1;
    }

    signal(SIGINT, on_signal);
    signal(SIGTERM, on_signal);
    srand((unsigned int)(time(NULL) ^ getpid()));

    ensure_dir(APP_ROOT);
    ensure_dir(IMAGE_DIR);
    ensure_dir(BEDTIME_IMAGE_DIR);
    ensure_dir(MUSIC_DIR);
    ensure_dir(STORY_DIR);
    ensure_dir(FONT_DIR);
    ensure_dir(CONFIG_DIR);
    init_alarm_defaults();
    load_config();
    app_log("system", "mk-piclock %s starting", APP_VERSION);

    int touch_available = (touch_init() == 0);
    if (touch_available) app_log("system", "TTP223B touch input initialized on GPIO %d", GPIO_TOUCH);
    else app_log("system", "TTP223B touch input unavailable on GPIO %d", GPIO_TOUCH);

    int led_available = (mp_led_init() == 0);
    if (led_available)
        app_log("system", "Common-cathode RGB LED initialized on GPIO %d/%d/%d",
                MP_LED_GPIO_RED, MP_LED_GPIO_GREEN, MP_LED_GPIO_BLUE);
    else
        app_log("system", "RGB LED unavailable on GPIO %d/%d/%d",
                MP_LED_GPIO_RED, MP_LED_GPIO_GREEN, MP_LED_GPIO_BLUE);
    update_led_scene();

    if (oled_init() == 0) {
        pthread_mutex_lock(&g_state.lock);
        g_state.oled_ok = 1;
        pthread_mutex_unlock(&g_state.lock);
        app_log("system", "OLED initialized");
        apply_bedtime_brightness();
        draw_startup_screen();
        sleep(STARTUP_GREETING_SECONDS);
        draw_clock_screen();
    } else {
        app_log("system", "OLED init failed, core IPC will still start");
        fprintf(stderr, "OLED init failed, core IPC will still start\n");
    }

    pthread_t ipc_thread;
    pthread_t touch_thread;
    int touch_thread_started = 0;
    app_log("system", "Private core IPC listening on %s", CORE_SOCKET_PATH);

    if (touch_available) {
        if (pthread_create(&touch_thread, NULL, touch_thread_main, NULL) == 0) {
            touch_thread_started = 1;
        } else {
            app_log("system", "Unable to start touch input thread");
            touch_close();
        }
    }

    if (pthread_create(&ipc_thread, NULL, ipc_thread_main, NULL) != 0) {
        perror("pthread_create");
        return 1;
    }

    int last_min = -1;
    int last_sec = -1;
    int last_mode = -1;
    int last_colon_phase = -1;
    int last_story_phase = -1;
    int last_wifi_status_state = -1;
    uint64_t last_diagnostic_refresh_ms = 0;
    while (g_running) {
        check_alarm();
        activate_pending_message_if_due();
        apply_bedtime_brightness();
        enforce_bedtime_music_policy();
        update_led_scene();

        pthread_mutex_lock(&g_state.lock);
        int mode = g_state.display_mode;
        int dirty = g_state.display_dirty;
        g_state.display_dirty = 0;
        int oled_ok = g_state.oled_ok;
        pthread_mutex_unlock(&g_state.lock);

        int marquee_active = 0;
        if (oled_ok) {
            if (mode == 2) {
                time_t until;
                char msg_image_file[IMAGE_FILE_MAX];
                int msg_image_bedtime;
                char msg_text[192];
                pthread_mutex_lock(&g_state.lock);
                until = g_state.message_until;
                safe_str(msg_image_file, sizeof(msg_image_file), g_state.message_image_file);
                msg_image_bedtime = g_state.message_image_bedtime;
                safe_str(msg_text, sizeof(msg_text), g_state.message_text);
                pthread_mutex_unlock(&g_state.lock);

                if (time(NULL) >= until) {
                    pthread_mutex_lock(&g_state.lock);
                    g_state.display_mode = 0;
                    g_state.message_until = 0;
                    pthread_mutex_unlock(&g_state.lock);
                    mode = 0;
                    last_mode = -1;
                } else if (dirty || mode != last_mode) {
                    draw_message_screen_file(msg_image_file, msg_image_bedtime, msg_text);
                }
            }

            if (mode == 3) {
                time_t diagnostic_until;
                pthread_mutex_lock(&g_state.lock);
                diagnostic_until = g_state.diagnostic_until;
                pthread_mutex_unlock(&g_state.lock);
                if (diagnostic_until <= 0 || time(NULL) >= diagnostic_until) {
                    close_diagnostic_screen();
                    pthread_mutex_lock(&g_state.lock);
                    mode = g_state.display_mode;
                    pthread_mutex_unlock(&g_state.lock);
                    last_mode = -1;
                } else {
                    uint64_t diagnostic_now_ms = monotonic_millis();
                    if (dirty || mode != last_mode ||
                        diagnostic_now_ms - last_diagnostic_refresh_ms >= DIAGNOSTIC_REFRESH_MS) {
                        draw_diagnostic_screen();
                        last_diagnostic_refresh_ms = diagnostic_now_ms;
                    }
                }
            }

            if (mode == 0) {
                time_t now = time(NULL);
                struct tm tmv;
                localtime_r(&now, &tmv);
                int colon_phase = clock_colon_blink_phase();
                int story_phase = story_display_phase();
                int wifi_status_state = wifi_status_render_state();
                marquee_active = song_metadata_marquee_active();
                if (dirty || mode != last_mode || tmv.tm_min != last_min || tmv.tm_sec != last_sec ||
                    colon_phase != last_colon_phase || story_phase != last_story_phase ||
                    clock_image_refresh_due()) {
                    last_min = tmv.tm_min;
                    last_sec = tmv.tm_sec;
                    last_colon_phase = colon_phase;
                    last_story_phase = story_phase;
                    last_wifi_status_state = wifi_status_state;
                    draw_clock_screen();
                } else if (marquee_active || wifi_status_state != last_wifi_status_state) {
                    last_wifi_status_state = wifi_status_state;
                    refresh_clock_footer();
                }
            } else if (mode == 1) {
                if (dirty || mode != last_mode) {
                    oled_clear_fb(0);
                    oled_flush_full();
                }
            }
        }

        last_mode = mode;
        usleep(marquee_active ? SONG_SCROLL_FRAME_US : 250000u);
    }

    if (touch_thread_started) pthread_join(touch_thread, NULL);
    touch_close();
    (void)audio_force_stop_and_wait(3000u);
    mp_led_shutdown();
    pthread_mutex_lock(&g_font.lock);
    font_cache_close_locked();
    pthread_mutex_unlock(&g_font.lock);
    oled_close();
    mpg123_exit();
    return 0;
}

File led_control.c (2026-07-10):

#define _GNU_SOURCE

#include "led_control.h"

#include <errno.h>
#include <gpiod.h>
#include <pthread.h>
#include <sched.h>
#include <stdint.h>
#include <stdio.h>
#include <string.h>
#include <time.h>

#define LED_GPIO_CHIP "/dev/gpiochip0"
#define LED_PWM_PERIOD_NS (1000000000LL / MP_LED_PWM_HZ)
#define LED_TRANSITION_MS 350ULL
#define LED_WRITE_FAILURE_LIMIT 5u
#define LED_RT_PRIORITY 10

struct led_runtime {
    pthread_mutex_t lock;
    pthread_cond_t changed;
    pthread_t thread;
    struct gpiod_chip *chip;
    struct gpiod_line_request *request;
    struct mp_led_profile profile;
    struct mp_led_global_settings settings;
    enum mp_led_scene scene;
    uint8_t colour_red;
    uint8_t colour_green;
    uint8_t colour_blue;
    uint8_t output_red;
    uint8_t output_green;
    uint8_t output_blue;
    uint8_t transition_colour_red;
    uint8_t transition_colour_green;
    uint8_t transition_colour_blue;
    uint8_t transition_output_red;
    uint8_t transition_output_green;
    uint8_t transition_output_blue;
    unsigned int write_errors;
    unsigned int consecutive_write_errors;
    uint64_t generation;
    uint64_t effect_started_ms;
    uint64_t transition_started_ms;
    int transition_active;
    int ready;
    int running;
    int thread_started;
};

static struct led_runtime g_led = {
    .lock = PTHREAD_MUTEX_INITIALIZER,
    .changed = PTHREAD_COND_INITIALIZER,
    .chip = NULL,
    .request = NULL,
    .profile = {0},
    .settings = {1, 100, 100, 65, 80, 0, 15, 1, 60, 255, 255, 255},
    .scene = MP_LED_SCENE_DAYTIME,
    .ready = 0,
    .running = 0,
    .thread_started = 0
};

static uint64_t monotonic_millis_led(void) {
    struct timespec now;
    clock_gettime(CLOCK_MONOTONIC, &now);
    return (uint64_t)now.tv_sec * 1000ULL + (uint64_t)now.tv_nsec / 1000000ULL;
}

static struct timespec timespec_add_ns(struct timespec base, int64_t ns) {
    base.tv_sec += (time_t)(ns / 1000000000LL);
    base.tv_nsec += (long)(ns % 1000000000LL);
    if (base.tv_nsec >= 1000000000L) {
        base.tv_sec++;
        base.tv_nsec -= 1000000000L;
    }
    return base;
}

static void sleep_until(struct timespec when) {
    while (clock_nanosleep(CLOCK_MONOTONIC, TIMER_ABSTIME, &when, NULL) == EINTR) {}
}

static int gpio_set_values(int red, int green, int blue) {
    if (!g_led.request) return -1;
    const enum gpiod_line_value values[3] = {
        red ? GPIOD_LINE_VALUE_ACTIVE : GPIOD_LINE_VALUE_INACTIVE,
        green ? GPIOD_LINE_VALUE_ACTIVE : GPIOD_LINE_VALUE_INACTIVE,
        blue ? GPIOD_LINE_VALUE_ACTIVE : GPIOD_LINE_VALUE_INACTIVE
    };
    int rc = gpiod_line_request_set_values(g_led.request, values);
    int disabled_now = 0;
    pthread_mutex_lock(&g_led.lock);
    if (rc == 0) {
        g_led.consecutive_write_errors = 0;
    } else {
        g_led.write_errors++;
        g_led.consecutive_write_errors++;
        if (g_led.consecutive_write_errors == LED_WRITE_FAILURE_LIMIT) {
            g_led.ready = 0;
            g_led.running = 0;
            disabled_now = 1;
            pthread_cond_broadcast(&g_led.changed);
        }
    }
    pthread_mutex_unlock(&g_led.lock);
    if (disabled_now) fprintf(stderr, "RGB LED disabled after repeated GPIO write failures\n");
    return rc;
}

static void all_off(void) {
    (void)gpio_set_values(0, 0, 0);
}

static uint8_t lerp_u8(uint8_t a, uint8_t b, uint64_t amount, uint64_t scale) {
    if (scale == 0 || amount == 0) return a;
    if (amount >= scale) return b;
    uint64_t left = (uint64_t)a * (scale - amount);
    uint64_t right = (uint64_t)b * amount;
    return (uint8_t)((left + right + scale / 2ULL) / scale);
}

static void rainbow_wheel(uint8_t pos, uint8_t *red, uint8_t *green, uint8_t *blue) {
    if (pos < 85u) {
        *red = (uint8_t)(255u - pos * 3u);
        *green = (uint8_t)(pos * 3u);
        *blue = 0;
    } else if (pos < 170u) {
        pos = (uint8_t)(pos - 85u);
        *red = 0;
        *green = (uint8_t)(255u - pos * 3u);
        *blue = (uint8_t)(pos * 3u);
    } else {
        pos = (uint8_t)(pos - 170u);
        *red = (uint8_t)(pos * 3u);
        *green = 0;
        *blue = (uint8_t)(255u - pos * 3u);
    }
}

static uint8_t gamma_u8(uint8_t value) {
    return (uint8_t)(((unsigned int)value * value + 127u) / 255u);
}

static uint8_t scale_output(uint8_t linear, uint8_t brightness, uint8_t maximum,
                            uint8_t gain, int enabled) {
    if (!enabled || linear == 0 || brightness == 0 || maximum == 0 || gain == 0) return 0;
    unsigned int effective = brightness < maximum ? brightness : maximum;
    unsigned int output = (unsigned int)linear * effective;
    output = (output + 50u) / 100u;
    output = (output * gain + 50u) / 100u;
    return (uint8_t)(output > 255u ? 255u : output);
}

static uint64_t effect_cycle_ms(const struct mp_led_profile *profile) {
    unsigned int seconds = profile->cycle_seconds;
    if (seconds < 2u) seconds = profile->effect == MP_LED_EFFECT_RAINBOW ? 12u : 8u;
    if (seconds > 60u) seconds = 60u;
    return (uint64_t)seconds * 1000ULL;
}
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

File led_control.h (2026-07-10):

#ifndef MK_PICLOCK_LED_CONTROL_H
#define MK_PICLOCK_LED_CONTROL_H

#include <stdint.h>

#include "ipc_protocol.h"

#define MP_LED_GPIO_RED 5
#define MP_LED_GPIO_GREEN 6
#define MP_LED_GPIO_BLUE 13
#define MP_LED_PWM_HZ 200
#define MP_LED_PWM_LEVELS 32

struct mp_led_status {
    enum mp_led_scene scene;
    uint8_t colour_red;
    uint8_t colour_green;
    uint8_t colour_blue;
    uint8_t output_red;
    uint8_t output_green;
    uint8_t output_blue;
    unsigned int write_errors;
    int ready;
};

int mp_led_init(void);
void mp_led_shutdown(void);
int mp_led_ready(void);
void mp_led_set_global(const struct mp_led_global_settings *settings);
void mp_led_set(enum mp_led_scene scene, const struct mp_led_profile *profile);
void mp_led_snapshot(struct mp_led_status *status);
const char *mp_led_scene_name(enum mp_led_scene scene);
const char *mp_led_effect_name(enum mp_led_effect effect);

#endif

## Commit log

2026-06-17 case design
    [221-base.stl, 221-lid.stl, mk-piclock-case-v2.21.scad]
2026-06-17 Add files via upload
    sample faces.
2026-06-21 add touch sensor
    [mk-piclock-case-v2.51.scad]
2026-06-21 add touch sensor.
2026-06-24 Update and rename mk-piclock-case-v2.32r.scad to mk-piclock-case-v2.62r.scad
    [mk-piclock-case-v2.62r.scad]
2026-07-07 added led - removed need for M2 for touch sensor.
    [mk-piclock-kids-v3.35.scad]
2026-07-08 includes proper snap charm
    [mk-piclock-kids-v3.35-clean-charm-insert.scad]
